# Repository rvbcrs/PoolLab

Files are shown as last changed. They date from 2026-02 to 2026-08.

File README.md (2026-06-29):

## Pura — ESP32‑S3 zwembadmonitor (pH, ORP, Temp · LVGL · MQTT · Zigbee)

### Wat het doet
- **pH en ORP meten** via analoge PH‑4502C/ORP‑4502C sensorbordjes (MCP6002 op 3.3 V) rechtstreeks op de ESP32 ADC.
- **Twee modi**: schakel tussen **Zigbee** en **WiFi/MQTT** via een UI‑toggle. De keuze wordt persistent opgeslagen (NVS) en bij boot toegepast.
- **MQTT integratie**: publiceert pH/ORP/temperatuur en biedt Home Assistant auto‑discovery + command topics om drempels te wijzigen.
- **Doseer‑pompen**: twee peristaltische pompen (pH/ORP) via TB6612FNG driver, met PWM‑snelheidsregeling vanuit de LVGL‑UI.
- **Safety**: limieten voor dagvolume, sessieduur en pH/ORP sanity; automatische noodstop + WhatsApp‑notificatie.
- **Zigbee commissioning**: lange druk op BOOT (>3 s) start commissioning; WiFi wordt tijdelijk uitgezet.

---

### Primaire hardware

| Onderdeel | Omschrijving |
|---|---|
| **MCU** | JC3248W535 — ESP32‑S3, 3.5" IPS 320×480 QSPI display, capacitief touch |
| **Sensoren** | 2× PH‑4502C bordje (één voor pH, één voor ORP), LM358 vervangen door **MCP6002** |
| **Motor driver** | SparkFun ROB‑14450 / TB6612FNG |
| **Pompen** | 2× peristaltische pomp (pH‑dosering en ORP/chloor‑dosering) |

---

### Sensor bekabeling (PH‑4502C met MCP6002 op 3.3 V)

> **Belangrijk:** Voed het bordje op **3.3 V**, niet 5 V.
> De MCP6002 is rail‑to‑rail (1.8–6 V). Bij 5 V kan de analoge output bij zuur water boven 3.3 V uitkomen en de ESP32 ADC beschadigen.

```
PH‑4502C (pH bordje)        JC3248W535 (ESP32‑S3)
  VCC  ──────────────────────  3.3 V
  GND  ──────────────────────  GND
  PO   ──────────────────────  GPIO6   (ADC1_CH5)
  DO   niet aansluiten
  TO   niet aansluiten
  BNC  ←── pH‑electrode

PH‑4502C (ORP bordje)       JC3248W535 (ESP32‑S3)
  VCC  ──────────────────────  3.3 V
  GND  ──────────────────────  GND
  PO   ──────────────────────  GPIO7   (ADC1_CH6)
  DO   niet aansluiten
  TO   niet aansluiten
  BNC  ←── ORP‑electrode
```

GPIO6 en GPIO7 zijn vrije ADC1‑pinnen (geen WiFi‑conflict). De overige ADC1‑pinnen zijn in gebruik door QSPI‑display (21/39/40/45/47/48), touch I2C (4/8), motoren (9/14–18) en I2S‑speaker (2/41/42).

**Testen zonder probe:**
Verbind de BNC center pin met de BNC outer ring via een 10 kΩ weerstand → simuleert 0 mV (pH 7 / 0 mV ORP) → de display toont ~pH 7.0 en ~0 mV.

**Platformio.ini flags (al ingesteld voor `esp32‑s3‑35`):**
```ini
-D USE_ANALOG_SENSORS=1
-D PH_ADC_PIN=6
-D ORP_ADC_PIN=7
```

**Kalibratie defaults (MCP6002 op 3.3 V, gain ≈ 5.2×):**
| Punt | Spanning |
|---|---|
| pH 4 | ≈ 2.58 V |
| pH 7 | ≈ 1.65 V (mid‑supply) |
| pH 10 | ≈ 0.72 V |
| ORP 0 mV | ≈ 1.65 V |

Kalibreer altijd met pH 4 en pH 7 buffervloeistof voor nauwkeurige metingen. Waarden worden opgeslagen in NVS via WebUI → Settings → Calibration.

---

### Wiring diagrams

**ESP32‑S3 — Analoge sensoren (PH‑4502C met MCP6002)**

```mermaid
flowchart LR
  PH_PROBE["pH‑electrode\n(BNC)"] --> PH_BOARD["PH‑4502C\n(MCP6002 op 3.3 V)"]
  ORP_PROBE["ORP‑electrode\n(BNC)"] --> ORP_BOARD["PH‑4502C ORP\n(MCP6002 op 3.3 V)"]
  PH_BOARD  --"PO → GPIO6"--> MCU["JC3248W535\nESP32‑S3"]
  ORP_BOARD --"PO → GPIO7"--> MCU
  V33["3.3 V"] --> PH_BOARD
  V33         --> ORP_BOARD
  GND["GND"]  --> PH_BOARD
  GND         --> ORP_BOARD
  GND         --> MCU
```

**ESP32‑C6 — ADS1115 via I2C**

```mermaid
flowchart LR
  PH_PROBE["pH‑electrode\n(BNC)"] --> PH_BOARD["PH‑4502C"]
  ORP_PROBE["ORP‑electrode\n(BNC)"] --> ORP_BOARD["PH‑4502C ORP"]
  PH_BOARD  --"AO → A0"--> ADS["ADS1115\n(0x48)"]
  ORP_BOARD --"AO → A1"--> ADS
  ADS --"SDA → GPIO18"--> MCU["ESP32‑C6"]
  ADS --"SCL → GPIO19"--> MCU
  V33["3.3 V"] --> ADS
  GND["GND"]   --> ADS
  GND          --> MCU
```

**ESP32‑S3 — Motor driver (TB6612FNG)**

```mermaid
flowchart LR
  MCU["JC3248W535\nESP32‑S3"] --"GPIO15 IN1\nGPIO16 IN2\nGPIO17 PWM"--> M1["TB6612\nMotor A"]
  MCU --"GPIO18 IN1\nGPIO14 IN2\nGPIO9 PWM"--> M2["TB6612\nMotor B"]
  MCU --"GPIO46 STBY"--> M1
  MCU --"GPIO46 STBY"--> M2
  M1 --"A01/A02"--> PUMP1["pH‑pomp"]
  M2 --"B01/B02"--> PUMP2["ORP‑pomp"]
  VM["6–12 V"] --> M1
  VM           --> M2
```

---

### ADS1115 (ESP32‑C6 build)

De C6‑build (`esp32‑c6‑147`) leest pH en ORP via een ADS1115 16‑bit ADC op I2C:

```
ADS1115          ESP32‑C6
  VDD ────────── 3.3 V
  GND ────────── GND
  SDA ────────── GPIO18
  SCL ────────── GPIO19
  A0  ────────── pH AO
  A1  ────────── ORP AO
```

Flags (al ingesteld):
```ini
-D USE_ADS1115=1
-D ADS_ADDR=0x48
-D ADS_SDA=18
-D ADS_SCL=19
-D ADS_CH_PH=0
-D ADS_CH_ORP=1
```

---

### Motor driver bekabeling (TB6612FNG — ESP32‑S3)

```
TB6612FNG        JC3248W535 (ESP32‑S3)
  VCC  ────────── 3.3 V  (logica)
  GND  ────────── GND
  VM   ────────── motorspanning (6–12 V)
  STBY ────────── GPIO46

  AIN1 ────────── GPIO15  (M1 IN1 / pH pomp)
  AIN2 ────────── GPIO16  (M1 IN2)
  PWMA ────────── GPIO17  (M1 PWM — LEDC CH5 / Timer 3)

  BIN1 ────────── GPIO18  (M2 IN1 / ORP pomp)
  BIN2 ────────── GPIO14  (M2 IN2)
  PWMB ────────── GPIO9   (M2 PWM — LEDC CH4 / Timer 2)

  A01/A02 ─────── Motor 1 (pH‑pomp)
  B01/B02 ─────── Motor 2 (ORP‑pomp)
```

- GPIO46 is een strapping pin; zorg dat STBY niet omlaag trekt tijdens boot.
- PWM: 10 kHz, 8‑bit. Snelheden instelbaar in LVGL‑UI en opgeslagen in NVS.

---

### Pump Flow Tracking & Kalibratie

**Wat wordt bijgehouden:**
- Real‑time flow rate (ml/min) tijdens pompen
- Session volume (ml) — reset bij stop
- Daily volume — reset automatisch om 00:00
- Total volume — handmatig reset via WebUI

**Flow kalibreren:**
1. WebUI → Settings → "Pump Flow Rate (ml/min @ 100%)"
2. Laat pomp 60 s @ 100% draaien, meet volume in maatbeker
3. Flow rate = gemeten volume / 1 minuut
4. Systeem schaalt automatisch voor lagere snelheden (bijv. 60% = 0.6 × gekalibreerde waarde)

---

### Safety Features & Emergency Stop

**Limieten (instelbaar in `src/main.cpp`):**
```cpp
MAX_DAILY_VOLUME     = 500.0f;  // ml/dag per pomp
MAX_SESSION_VOLUME   = 200.0f;  // ml per aanslag
MAX_SESSION_DURATION = 120;     // seconden per aanslag
PH_SANITY_MIN        = 4.0f;
PH_SANITY_MAX        = 10.0f;
ORP_SANITY_MIN       = -500.0f;
ORP_SANITY_MAX       = 1500.0f;
SENSOR_TIMEOUT       = 300;     // seconden zonder data → alarm
```

**Gedrag bij trigger:**
- Alle pompen direct gestopt
- Rode banner op LVGL UI: `⚠️ EMERGENCY STOP - <reden>`
- MQTT alert op `pool/alert/<type>`
- WhatsApp‑bericht via CallMeBot

**WhatsApp Setup (CallMeBot):**
1. Verkrijg API key via https://www.callmebot.com/blog/free-api-whatsapp-messages/
2. WebUI → Safety → telefoonnummer (bijv. `31612345678`) + API key invullen
3. Test via "Send Test Alert" button

**MQTT Alert Topics:**
```
pool/alert/daily_limit_m1      pool/alert/daily_limit_m2
pool/alert/session_volume_m1   pool/alert/session_volume_m2
pool/alert/session_duration_m1 pool/alert/session_duration_m2
pool/alert/ph_sanity_low       pool/alert/ph_sanity_high
pool/alert/orp_sanity_low      pool/alert/orp_sanity_high
pool/alert/ph_sensor_timeout   pool/alert/orp_sensor_timeout
```

---

### Bouwen en flashen

Primaire build (ESP32‑S3 35"):
```bash
pio run -e esp32-s3-35 -t upload --upload-port <ip>   # OTA
pio run -e esp32-s3-35 -t upload                       # USB
```

C6 build:
```bash
pio run -e esp32-c6-147 -t upload
```

Seriële monitor: 115200 baud.

---

### Configuratie

**WiFi** via captive portal:
- Bij lege WiFi‑gegevens start automatisch AP `Pura‑Setup`.
- Verbind → open willekeurige URL → vul SSID/wachtwoord in → Save & Reboot.
- Of via Settings → Network → Configure WiFi.

**MQTT** instelbaar via WebUI → Settings (host/port/user/pass) of in `src/main.cpp`:
```cpp
MQTT_HOST, MQTT_PORT, MQTT_USER, MQTT_PASS, MQTT_CLIENTID
```

**OTA:** hostnaam `pura-XXXXXX` (chip‑ID). Upload via PlatformIO "Upload using network" of ArduinoOTA.

---

### MQTT Topics

State:
```
pool/sensor/ph
pool/sensor/orp
pool/sensor/temp
```

Home Assistant discovery:
```
homeassistant/sensor/pool_ph/config
homeassistant/sensor/pool_orp/config
homeassistant/sensor/pool_temp/config
```

Drempels (write/echo):
```
pool/cmd/ph_min  ↔  pool/cfg/ph_min
pool/cmd/ph_max  ↔  pool/cfg/ph_max
pool/cmd/orp_min ↔  pool/cfg/orp_min
pool/cmd/orp_max ↔  pool/cfg/orp_max
```

---

### WebUI

| URL | Pagina |
|-----|---|
| `http://<ip>/` | Live sensor tiles + pump stats (WebSocket) |
| `http://<ip>/settings` | pH/ORP drempels, pompsnelheden, flow kalibratie, MQTT |
| `http://<ip>/safety` | Emergency status, WhatsApp config, volume resets, test alerts |

WebSocket op poort 81.

---

### LVGL UI

- **ESP32‑S3 (3.5"):** 3‑card UI (pH / ORP / Temp), moderne donkere tegels, pump stats boven motoricoon, emergency banner.
- **ESP32‑C6 (1.47"):** Compacte tileview (pH/ORP).
- Watchdog S3: heartbeat uit BSP‑task; herbouwt UI als >8 s stil → `S3 LVGL watchdog: rebuild complete`.
- Touch: debouncing ingebouwd, geen key‑repeat.

---

### Projectstructuur

| Bestand | Rol |
|---|-----|
| `src/main.cpp` | Bootvolgorde, WiFi/MQTT, Zigbee, periodic publish, safety |
| `src/core/Storage.{h,cpp}` | NVS wrapper (drempels, snelheden, modus, volumes, config) |
| `src/core/boards/Esp32S3Board.{h,cpp}` | S3 board: display, touch, pins, LVGL lock |
| `src/core/boards/Esp32C6Board.{h,cpp}` | C6 board |
| `src/boards/BoardSelect.{h,cpp}` | Board‑selectie op basis van build flag |
| `src/domain/Metrics.{h,cpp}` | Laatste pH/ORP/temp; bron voor UI en MQTT |
| `src/domain/ControlPolicy.{h,cpp}` | Safety logic, sanity checks, emergency stop |
| `src/io/AnalogPhOrpSensor.h` | ADC‑lezer voor PH‑4502C via ESP32 ADC (S3) |
| `src/io/AdsPhOrpSensor.{h,cpp}` | ADS1115 I2C lezer voor pH/ORP (C6) |
| `src/io/MotorController.h` | Motor state machine, LEDC PWM, flow tracking |
| `src/io/MqttClient.{h,cpp}` | PubSubClient: discovery, publish, command topics, alerts |
| `src/io/WebUI.{h,cpp}` | Async web server: homepage, settings, safety, WebSocket, API |
| `src/io/ZigbeeClient.{h,cpp}` | Zigbee abstractie (C6; no‑op op S3) |
| `src/ui/UI.{h,cpp}` | LVGL UI builder (3‑card S3 / tileview C6), emergency banner |
| `src/domain/DummySensor.h` | Gesimuleerde sensordata voor testen |
| `src/fonts`, `src/images` | LVGL assets (fonts, iconen) |

---

### Troubleshooting

**pH/ORP waarden kloppen niet:**
- Kalibreer met pH 4 en pH 7 buffervloeistof via WebUI → Settings → Calibration.
- Check de spanning op PO met een multimeter: bij VCC=3.3 V moet pH 7 ≈ 1.65 V geven.
- Zorg dat VCC van het sensorbordje echt 3.3 V is (niet 5 V).

**WiFi "NO_AP_FOUND":** controleer SSID/ontvangst; auto‑reconnect + periodieke hard restart.

**MQTT extern werkt niet, lokaal wel:**
- Cloudflare DNS: zet op "DNS only" (grijze wolk) voor raw TCP.
- NPM: gebruik Streams (TCP), geen Proxy Host.
- Test met `mosquitto_sub/pub` voordat je het device test.

**Pompen werken niet:**
- Console: `[MOTOR] Check: MOTOR_ENABLE=1 motorsEnabled=?` — beide moeten 1 zijn.
- WebUI → Settings → vink "Enable pH/ORP dosing pumps" aan → Save.

**Emergency stop reset niet automatisch:**
- Sanity alerts: wacht tot sensorwaarden terug binnen limieten zijn.
- Volume/duration limits: reset device of wacht tot 00:00 (daily reset).

**WhatsApp notificaties werken niet:**
- Telefoonnummer met landcode (bijv. `31612345678`).
- Test via CallMeBot website om te bevestigen dat account actief is.
- Console: zoek naar `[SAFETY] WhatsApp API response: 200`.

---

### Changelog

**Huidig:**
- ✅ Tuya UART sniffer verwijderd — alle sensordata nu via directe hardware (ADC / ADS1115).
- ✅ PH‑4502C analoge sensoren op GPIO6 (pH) en GPIO7 (ORP) — MCP6002 op 3.3 V.
- ✅ Kalibratie defaults aangepast voor MCP6002 op 3.3 V (mid‑supply = 1.65 V).
- ✅ Zigbee `onPh/OrpMinMaxWrite` stubs voor non‑Zigbee builds (fix compile‑fout S3).
- ✅ `core::Board.h` include toegevoegd aan `UI.cpp` (fix `UiConfig` compile‑fout).
- ✅ Backup‑bestanden opgeruimd (`AnalogPhOrpSensor 2.h`, `AdsPhOrpSensor 2.*`).

**Eerder:**
- ✅ Pump flow tracking: ml/min, session, daily (auto‑reset 00:00), total.
- ✅ Safety limits: daily/session volume, session duration, pH/ORP sanity, sensor timeout.
- ✅ Emergency stop: noodstop + rode LVGL banner.
- ✅ WhatsApp notificaties via CallMeBot (async task).
- ✅ MQTT alert topics `pool/alert/<type>`.
- ✅ WebUI Safety page, Settings gereorganiseerd met emoji‑headers.
- ✅ Unieke MQTT clientId per device (chip‑ID).
- ✅ Exponential backoff bij MQTT reconnect.
- ✅ LVGL watchdog voor C6 en S3.
- ✅ Touch debouncing (geen key‑repeat).
- ✅ Reset WiFi knop via captive portal.

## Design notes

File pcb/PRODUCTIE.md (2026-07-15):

# Pura mainboard — van bron naar productie-PCB (rev 0.3, 0805)

Flow: **`python3 build_flow.py`** — tscircuit (bron) → KiCad → freerouting (headless) → DRC-schoon board, volautomatisch. Daarna alleen nog silk/gerbers/bestellen.
Klaarstaand voor deze revisie: map **`pura-mainboard-0805-0.3.kicad/`** (met GND-zones + het **nieuwe rev 0.3 AGND-eiland** uit `port_zones.py`, al gevuld en DRC-gecheckt)
**Verificatiestatus: zie `VERIFICATIE-0.3.md`** — alle import-pinmappings, pin-coverage en custom lands zijn datasheet-geverifieerd.

## 0. Openstaande beslissingen (vóór je begint)

- [x] **C_OUT**: besloten — **220µF/16V SMD-elco (Ø6.3 V-chip)**, zit in de 0.3-bron. Polariteit: **pin 1 = +** naar de 5V-rail; de zwarte minstreep van de cup hoort aan de GND-kant.
- [ ] **Elco-maat meten**: TME-nummers zijn **EEE-1EA101XP / EEE-1CA221XP** (X = Ø6.3 case D8). De varianten *zonder* X zijn Ø8 en passen NIET op de lands. Meet ook de al via Ali bestelde 100 µF (moet Ø6.3 zijn).
- [ ] **LCSC-nummers invullen** in `pura-bom.csv` voor alle `TBD`-regels (0805-weerstanden/condensatoren/LEDs, 100µF 25V, 24k). Alleen nodig bij JLC-assembly; bij handmontage met AliExpress-onderdelen (Component Bench) niet.
- [x] Klopt de **24k op CFG1** met de CH224K-datasheet-tabel (6.8k=9V, **24k=12V**, 56k=15V)? ✔ Nagelezen én pin 9=CFG1 in de footprint geverifieerd tegen de pinout-figuur (§4.1) — zie `VERIFICATIE-0.3.md`.

## 1–4. Volautomatische flow: `build_flow.py`

Alles van tsx-bron tot geroute, DRC-schoon board is één commando:

```bash
cd pcb
python3 build_flow.py              # hele flow (incl. tsci-export)
python3 build_flow.py --no-export  # tsx ongewijzigd: sla de export over
```

De flow doet achtereenvolgens:

1. **tsci-export** (kicad_zip) + hernoemen naar de 0.3-bestandsnamen
2. **netklassen + rules** in de `.kicad_pro`: Default 0.2 mm (via 0.6/0.3), **POWER 0.6 mm** (via 0.8/0.4) voor 12V-VBUS, buck-switchnode, 5V-rail en de 4 motoruitgangen; min. track/clearance 0.15, edge 0.4, thermal spokes 1. (tsci schrijft schema-v1; de flow normaliseert naar v5, anders dropt KiCad de klasse-toewijzingen!)
3. **zones porten** (`port_zones.py`): GND prio 1/2 + AGND-eiland v2, tsci's auto-zones eruit
4. **gelockte pre-routes** (`preroute_iso.py`, met eigen clearance-validator): iso-netten binnen het eiland, AIN0/AIN1 (pH/ORP) door de gang onderlangs, en het complete AGND-stitching-raamwerk (pad-verankerd)
5. **3D-modellen** injecteren voor de custom footprints (L1 → `L_APV_ANR6045`, C_IN/C_OUT → `CP_Elec_6.3x7.7`)
6. **DSN bouwen** (tijdelijke kopie zonder zones, clearance 0.17 als afrondmarge)
7. **freerouting headless** (`~/Downloads/freerouting-1.7.0.jar`, `-mp 200`) — de gelockte sporen gaan als `type fix` mee en blijven staan
8. **ses importeren** + opschonen (AGND-sporen buiten het eiland weg, dubbelen weg) + zone-fill + **adaptieve AGND-stitching** (raster-vias, alleen waar beide lagen fill hebben)
9. **DRC-gate**: faalt hard op unconnected/clearance/shorts/edge; silk/tekst-cosmetica mag

> ⚠️ De freerouting-**GUI** (v2.2.4) crasht met `StackOverflowError` op deze DSN — daarom headless met de 1.7.0-jar. Niet meer handmatig DSN'en/importeren.
> ⚠️ Handmatige board-edits (silk, verplaatsingen) overleven een flow-run **niet** — de bron is de tsx. Backups: `*.goodhand.bak` e.d. in de kicad-map.
> Los valideren van de bron kan nog steeds: `npx tsci export pura-mainboard-noroute.tsx -f circuit-json -o circuit.json` (0 errors verwacht).

Na de flow: board openen in KiCad voor de visuele check + silkscreen/logo/versienummer **v0.3**, daarna stap 5.

## 5. Productiebestanden exporteren (KiCad)

**Gerbers** — `File > Fabrication Outputs > Gerbers`:
- Lagen: F.Cu, B.Cu, F.Mask, B.Mask, F.Silkscreen, B.Silkscreen, Edge.Cuts
- Opties: Protel-extensies **uit**, "subtract soldermask from silk" **aan**
- `Generate Drill Files`: Excellon, PTH+NPTH samengevoegd mag
- Alles in één map → zip: `pura-mainboard-0805-0.3-gerbers.zip`

**Assembly (alleen bij JLC-SMT):**
- BOM: `pura-bom.csv` (eerst TBD's → echte LCSC-nummers; kolommen Designator/Comment/Footprint/LCSC)
- CPL: `File > Fabrication Outputs > Component Placement (.pos)` → CSV met kolommen `Designator, Mid X, Mid Y, Layer, Rotation` (JLC-format, zie `pura-cpl-jlcpcb.csv` van rev 0.2 als voorbeeld)

> ⚠️ `make_bom.py` **overschrijft** de handmatig verrijkte `pura-bom.csv` — niet draaien tenzij je de LCSC-kolom opnieuw wilt invullen.

## 6. Bestellen bij JLCPCB

1. Gerber-zip uploaden → controleer de render (outline 50×50 mm, 2 lagen)
2. PCB-opties: 1.6 mm FR-4, 2 laags, HASL of ENIG, kleur naar smaak — verder defaults
3. **Met assembly**: SMT Assembly aanvinken (top side) → BOM + CPL uploaden → parts matchen (streef naar basic parts voor de passives; extended = ~$3 setup per uniek onderdeel) → **placement-preview**: rotaties van U1–U6, D1, LEDs en J1 visueel controleren en zo nodig draaien (tab-fouten hier = dode boards)
4. **Zonder assembly** (handmontage): alleen de gerber-zip; onderdelen bestel je via de Component Bench (`python3 ali_server.py`) — zie `pura-self-source.csv`
5. DFM-opmerkingen van JLC afwachten → bevestigen

## 7. Bring-up checklist (als de boards binnen zijn)

1. Visuele inspectie: bruggen bij U3 (VSSOP-10, 0.5 mm pitch) en U4 (SSOP-24)
2. Multimeter, **vóór** aansluiten: geen kortsluiting VBUS↔GND, 5V↔GND, AGND↔GND (moet ~∞, AGND↔GND alleen via de isolatie gescheiden)
3. USB-C PD-lader aansluiten → **VBUS = 12 V** meten (dit valideert de CFG1/24k-fix; 5 V = config fout)
4. 5V-rail meten na de LM2596 (4.9–5.1 V), rimpel checken als je een scoop hebt
5. ESP + firmware: I²C-scan moet de ADS1115 op **0x48** zien (valideert R_ADDR/soldeerbrug)
6. Pompen los testen op de TB6612-uitgangen (12 V blokgolf bij PWM)
7. pH/ORP-proefmeting via de geïsoleerde ingang; waardes vergelijken met buffer

## Bekende afwijkingen t.o.v. rev 0.2 (de geproduceerde boards)

| Wat | rev 0.2 (besteld) | rev 0.3 (deze flow) |
|---|---|---|
| Passives | 0402/0603 | **0805** |
| CH224K config | 0R op CFG2 → vraagt 5 V (bug!) | **24k op CFG1 → 12 V** |
| C_IN | C15008 = 6.3 V (te laag op 12 V-rail) | **100µF 25 V** |
| C_OUT | C15008 (MLCC) | **220µF 16 V SMD-elco** (Ø6.3) |
| L1 | 33µH **1210, 70mA** (RF-choke!) | **33µH CD54 power-inductor ~0.7A** (5.8×5.2mm) |
| CH224K-voeding | VDD **direct aan 12 V** (abs max 3,6 V — chip sterft!) | **1 kΩ serie + 1 µF** (R_VDD/C_VDD), VBUS-sense via **10 kΩ** (R_VSNS) |
| CC-pulldowns | externe 5,1 kΩ (fout: Rd zit intern) | **vervallen** — CC1/CC2 direct |
| DP/DM | zwevend | **kortgesloten** (PD-only, datasheet §5.5) |
| TB6612 VCC | 5 V (VIH=3,5 V > 3,3 V ESP: buiten spec) | **3,3 V via nieuwe V33-pin** op J_ESP (11-pins!) |
| ADuM1250 | ESP aan side 1 (VOL 0,9 V > ESP-drempel) | **omgedraaid**: ESP aan side 2 @3,3 V + pull-ups R_SDA2/R_SCL2 |
| B0505S | geen minimumbelasting (Vout kan ~6 V worden) | **R_BLD 330 Ω** op V5_ISO |

> ⚠️ **Rev 0.2-boards: de PD-sectie is NIET veilig te bodgen.** Naast de CFG-fout ligt daar CH224K-VDD **rechtstreeks aan 12 V** (abs max 3,6 V) — de chip gaat direct stuk zodra een PD-lader 12 V levert. Repareren vergt trace-snijden + 2 weerstanden + zijden-swap van de ADuM: niet realistisch. Gebruik rev 0.2 hooguit als soldeeroefening; bouw op rev 0.3.

**Let op de ESP-kabel:** J_ESP is nu **11-pins** — er is een **V33-ader bij** (3,3 V vanuit de ESP-module) die TB6612 en de ADuM-ESP-kant voedt. Zonder die ader doen de pompen en de I²C het niet.

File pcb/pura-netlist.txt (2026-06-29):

COMPONENTS:
 - J1: TYPE_C_16PIN_2MD_073_
 - U1: CH224K
 - R_CC1: 5.1kΩ res0402 resistor
 - R_CC2: 5.1kΩ res0402 resistor
 - R_CFG2: 0Ω res0402 resistor
 - C_VDD: 100nF 0402 capacitor
 - C_IN: 220uF 1210 capacitor
 - U2: LM2596S_5_0_UMW_
 - C_OUT: 220uF 1210 capacitor
 - D1: D1, source_component
 - L1: L1, source_component
 - C_DC_IN: 10uF 0603 capacitor
 - U5: B0505S_1WR3
 - C_DC_OUT: 10uF 0603 capacitor
 - C_ISO1: 100nF 0402 capacitor
 - U6: ADUM1250ARZ_RL7
 - C_ISO2: 100nF 0402 capacitor
 - R_SDA: 4.7kΩ res0402 resistor
 - R_SCL: 4.7kΩ res0402 resistor
 - U3: ADS1115IDGST
 - C_ADS: 100nF 0402 capacitor
 - R_ADDR: 0Ω res0402 resistor
 - C_VM: 10uF 0603 capacitor
 - U4: TB6612FNG_C_8_EL
 - C_VCC: 100nF 0402 capacitor
 - R_LED: 2.2kΩ res0402 resistor
 - LED1: LED1, source_component
 - R_LED2: 2.2kΩ res0402 resistor
 - LED2: LED2, source_component
 - J_ESP: J_ESP, source_component
 - J_PROBE: J_PROBE, source_component
 - J_M1: J_M1, source_component
 - J_M2: J_M2, source_component
 - J_12V: J_12V, source_component

NET: R_CC1_pos
  - J1 B5
  - U1 CC1
  - R_CC1 pin1

NET: R_CC2_pos
  - J1 A5
  - U1 CC2
  - R_CC2 pin1

NET: R_CFG2_pos
  - U1 CFG2
  - R_CFG2 pin1

NET: U2_OUT
  - U2 OUT
  - L1 pin1 (+)
  - D1 pin2 (-)

NET: LED1_pos
  - R_LED pin2
  - LED1 pin1 (+)

NET: LED2_pos
  - R_LED2 pin2
  - LED2 pin1 (+)

NET: U3_VDD
  - C_ISO2 pin1 (+)
  - U5 pin4
  - U6 VDD2
  - U3 VDD
  - J_PROBE V5_ISO
  - R_LED2 pin1
  - C_DC_OUT pin1 (+)
  - R_SDA pin2
  - R_SCL pin2
  - C_ADS pin1 (+)

NET: U3_ADDR
  - U3 ADDR
  - R_ADDR pin1

NET: AGND
  - R_ADDR pin2
  - C_ADS pin2 (-)
  - C_ISO2 pin2 (-)
  - C_DC_OUT pin2 (-)
  - LED2 pin2 (-)
  - U5 pin3
  - U6 GND2
  - U3 GND
  - J_PROBE AGND

NET: U3_SDA
  - U3 SDA
  - R_SDA pin1
  - U6 SDA2

NET: U3_SCL
  - U3 SCL
  - R_SCL pin1
  - U6 SCL2

NET: J_PROBE_PH_PO
  - U3 AIN0
  - J_PROBE PH_PO

NET: J_PROBE_ORP_PO
  - U3 AIN1
  - J_PROBE ORP_PO

NET: J_ESP_SDA
  - J_ESP SDA
  - U6 SDA1

NET: J_ESP_SCL
  - J_ESP SCL
  - U6 SCL1

NET: GND
  - C_VCC pin2 (-)
  - C_VM pin2 (-)
  - C_ISO1 pin2 (-)
  - C_DC_IN pin2 (-)
  - LED1 pin2 (-)
  - U2 EP
  - U2 pin5
  - C_OUT pin2 (-)
  - D1 pin1 (+)
  - C_IN pin2 (-)
  - U2 GND
  - C_VDD pin2 (-)
  - R_CFG2 pin2
  - R_CC2 pin2
  - R_CC1 pin2
  - U1 GND
  - J1 A1B12
  - J1 B1A12
  - J1 EH1
  - J1 EH2
  - U4 GND
  - U4 PGND11
  - U4 PGND21
  - J_ESP GND
  - J_12V GNDP
  - U6 GND1
  - U5 pin1

NET: U1_VDD
  - C_IN pin1 (+)
  - U1 VDD
  - U1 VBUS
  - C_VDD pin1 (+)
  - J1 A4B9
  - J1 B4A9
  - U2 VIN
  - U4 VM1
  - J_12V VIN12
  - C_VM pin1 (+)
  - U4 VM2
  - U4 VM3

NET: U4_PWMA
  - U4 PWMA
  - J_ESP PWMA

NET: U4_PWMB
  - U4 PWMB
  - J_ESP PWMB

NET: U4_AIN1
  - U4 AIN1
  - J_ESP AIN1

NET: U4_AIN2
  - U4 AIN2
  - J_ESP AIN2

NET: U4_BIN1
  - U4 BIN1
  - J_ESP BIN1

NET: U4_BIN2
  - U4 BIN2
  - J_ESP BIN2

NET: U2_FB
  - U4 STBY
  - C_ISO1 pin1 (+)
  - L1 pin2 (-)
  - U2 FB
  - C_OUT pin1 (+)
  - U4 VCC
  - J_ESP V5
  - U6 VDD1
  - U5 pin2
  - R_LED pin1
  - C_DC_IN pin1 (+)
  - C_VCC pin1 (+)

NET: U4_AO11
  - U4 AO11
  - J_M1 MA1

NET: U4_AO21
  - U4 AO21
  - J_M1 MA2

NET: U4_BO11
  - U4 BO11
  - J_M2 MB1

NET: U4_BO21
  - U4 BO21
  - J_M2 MB2

COMPONENT_PINS:
J1 (TYPE_C_16PIN_2MD_073_)
- pin1: NOT_CONNECTED
- pin2: NOT_CONNECTED
- pin3: NOT_CONNECTED
- pin4: NOT_CONNECTED
- pin5: NOT_CONNECTED
- pin6: NOT_CONNECTED
- pin7: NOT_CONNECTED
- pin8: NOT_CONNECTED
- pin9: NOT_CONNECTED
- pin10: NOT_CONNECTED
- pin11: NOT_CONNECTED
- pin12: NOT_CONNECTED
- pin13(EH1): NETS(GND)
- pin14(EH2): NETS(GND)
- pin15(pin13_alt1): NOT_CONNECTED
- pin16(pin14_alt1): NOT_CONNECTED
- pin17(A1B12): NETS(GND)
- pin18(A4B9): NETS(U1_VDD)
- pin19(B8): NOT_CONNECTED
- pin20(A5): NETS(R_CC2_pos)
- pin21(B7): NOT_CONNECTED
- pin22(A6): NOT_CONNECTED
- pin23(A7): NOT_CONNECTED
- pin24(B6): NOT_CONNECTED
- pin25(A8): NOT_CONNECTED
- pin26(B5): NETS(R_CC1_pos)
- pin27(B4A9): NETS(U1_VDD)
- pin28(B1A12): NETS(GND)

U1 (CH224K)
- pin1(VDD): NETS(U1_VDD)
- pin2(CFG2): NETS(R_CFG2_pos)
- pin3(CFG3): NOT_CONNECTED
- pin4(DP): NOT_CONNECTED
- pin5(DM): NOT_CONNECTED
- pin6(CC2): NETS(R_CC2_pos)
- pin7(CC1): NETS(R_CC1_pos)
- pin8(VBUS): NETS(U1_VDD)
- pin9(CFG1): NOT_CONNECTED
- pin10(PG): NOT_CONNECTED
- pin11(GND): NETS(GND)

R_CC1 (5.1kΩ res0402)
- pin1(anode, pos, left): NETS(R_CC1_pos)
- pin2(cathode, neg, right): NETS(GND)

R_CC2 (5.1kΩ res0402)
- pin1(anode, pos, left): NETS(R_CC2_pos)
- pin2(cathode, neg, right): NETS(GND)

R_CFG2 (0Ω res0402)
- pin1(anode, pos, left): NETS(R_CFG2_pos)
- pin2(cathode, neg, right): NETS(GND)

C_VDD (100nF 0402)
- pin1(pos, anode, left): NETS(U1_VDD)
- pin2(neg, cathode, right): NETS(GND)

C_IN (220uF 1210)
- pin1(pos, anode, left): NETS(U1_VDD)
- pin2(neg, cathode, right): NETS(GND)

U2 (LM2596S_5_0_UMW_)
- pin1(VIN): NETS(U1_VDD)
- pin2(OUT): NETS(U2_OUT)
- pin3(GND): NETS(GND)
- pin4(FB): NETS(U2_FB)
- pin5: NETS(GND)
- pin6(EP): NETS(GND)

C_OUT (220uF 1210)
- pin1(pos, anode, left): NETS(U2_FB)
- pin2(neg, cathode, right): NETS(GND)

D1 (SS34)
- pin1(pos, anode, left): NETS(GND)
- pin2(neg, cathode, right): NETS(U2_OUT)

L1
- pin1(anode, pos, left): NETS(U2_OUT)
- pin2(cathode, neg, right): NETS(U2_FB)

C_DC_IN (10uF 0603)
- pin1(pos, anode, left): NETS(U2_FB)
- pin2(neg, cathode, right): NETS(GND)

U5 (B0505S_1WR3)
- pin1: NETS(GND)
- pin2: NETS(U2_FB)
- pin3: NETS(AGND)
- pin4: NETS(U3_VDD)

C_DC_OUT (10uF 0603)
- pin1(pos, anode, left): NETS(U3_VDD)
- pin2(neg, cathode, right): NETS(AGND)

C_ISO1 (100nF 0402)
- pin1(pos, anode, left): NETS(U2_FB)
- pin2(neg, cathode, right): NETS(GND)

U6 (ADUM1250ARZ_RL7)
- pin1(VDD1): NETS(U2_FB)
- pin2(SDA1): NETS(J_ESP_SDA)
- pin3(SCL1): NETS(J_ESP_SCL)
- pin4(GND1): NETS(GND)
- pin5(GND2): NETS(AGND)
- pin6(SCL2): NETS(U3_SCL)
- pin7(SDA2): NETS(U3_SDA)
- pin8(VDD2): NETS(U3_VDD)

C_ISO2 (100nF 0402)
- pin1(pos, anode, left): NETS(U3_VDD)
- pin2(neg, cathode, right): NETS(AGND)

R_SDA (4.7kΩ res0402)
- pin1(anode, pos, left): NETS(U3_SDA)
- pin2(cathode, neg, right): NETS(U3_VDD)

R_SCL (4.7kΩ res0402)
- pin1(anode, pos, left): NETS(U3_SCL)
- pin2(cathode, neg, right): NETS(U3_VDD)

U3 (ADS1115IDGST)
- pin1(ADDR): NETS(U3_ADDR)
- pin2: NOT_CONNECTED
- pin3(GND): NETS(AGND)
- pin4(AIN0): NETS(J_PROBE_PH_PO)
- pin5(AIN1): NETS(J_PROBE_ORP_PO)
- pin6(AIN2): NOT_CONNECTED
- pin7(AIN3): NOT_CONNECTED
- pin8(VDD): NETS(U3_VDD)
- pin9(SDA): NETS(U3_SDA)
- pin10(SCL): NETS(U3_SCL)

C_ADS (100nF 0402)
- pin1(pos, anode, left): NETS(U3_VDD)
- pin2(neg, cathode, right): NETS(AGND)

R_ADDR (0Ω res0402)
- pin1(anode, pos, left): NETS(U3_ADDR)
- pin2(cathode, neg, right): NETS(AGND)

C_VM (10uF 0603)
- pin1(pos, anode, left): NETS(U1_VDD)
- pin2(neg, cathode, right): NETS(GND)

U4 (TB6612FNG_C_8_EL)
- pin1(AO11): NETS(U4_AO11)
- pin2(AO12): NOT_CONNECTED
- pin3(PGND11): NETS(GND)
- pin4(PGND12): NOT_CONNECTED
- pin5(AO21): NETS(U4_AO21)
- pin6(AO22): NOT_CONNECTED
- pin7(BO21): NETS(U4_BO21)
- pin8(BO22): NOT_CONNECTED
- pin9(PGND21): NETS(GND)
- pin10(PGND22): NOT_CONNECTED
- pin11(BO11): NETS(U4_BO11)
- pin12(BO12): NOT_CONNECTED
- pin13(VM2): NETS(U1_VDD)
- pin14(VM3): NETS(U1_VDD)
- pin15(PWMB): NETS(U4_PWMB)
- pin16(BIN2): NETS(U4_BIN2)
- pin17(BIN1): NETS(U4_BIN1)
- pin18(GND): NETS(GND)
- pin19(STBY): NETS(U2_FB)
- pin20(VCC): NETS(U2_FB)
- pin21(AIN1): NETS(U4_AIN1)
- pin22(AIN2): NETS(U4_AIN2)
- pin23(PWMA): NETS(U4_PWMA)
- pin24(VM1): NETS(U1_VDD)

C_VCC (100nF 0402)
- pin1(pos, anode, left): NETS(U2_FB)
- pin2(neg, cathode, right): NETS(GND)

R_LED (2.2kΩ res0402)
- pin1(anode, pos, left): NETS(U2_FB)
- pin2(cathode, neg, right): NETS(LED1_pos)

LED1
- pin1(anode, pos, left): NETS(LED1_pos)
- pin2(cathode, neg, right): NETS(GND)

R_LED2 (2.2kΩ res0402)
- pin1(anode, pos, left): NETS(U3_VDD)
- pin2(cathode, neg, right): NETS(LED2_pos)

LED2
- pin1(anode, pos, left): NETS(LED2_pos)
- pin2(cathode, neg, right): NETS(AGND)

J_ESP
- pin1(V5): NETS(U2_FB)
- pin2(GND): NETS(GND)
- pin3(SDA): NETS(J_ESP_SDA)
- pin4(SCL): NETS(J_ESP_SCL)
- pin5(PWMA): NETS(U4_PWMA)
- pin6(PWMB): NETS(U4_PWMB)
- pin7(AIN1): NETS(U4_AIN1)
- pin8(AIN2): NETS(U4_AIN2)
- pin9(BIN1): NETS(U4_BIN1)
- pin10(BIN2): NETS(U4_BIN2)

J_PROBE
- pin1(V5_ISO): NETS(U3_VDD)
- pin2(AGND): NETS(AGND)
- pin3(PH_PO): NETS(J_PROBE_PH_PO)
- pin4(ORP_PO): NETS(J_PROBE_ORP_PO)

J_M1
- pin1(MA1): NETS(U4_AO11)
- pin2(MA2): NETS(U4_AO21)

J_M2
- pin1(MB1): NETS(U4_BO11)
- pin2(MB2): NETS(U4_BO21)

J_12V
- pin1(VIN12): NETS(U1_VDD)
- pin2(GNDP): NETS(GND)

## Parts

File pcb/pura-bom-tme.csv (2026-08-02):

Designator | Qty | Value | Footprint | Manufacturer | MPN | Bron | Note
R_CFG1 | 1 | 24k 1% | 0805 | Yageo | RC0805FR-0724KL | Ali (0603-set) | CH224K -> 12V request; 0603 uit assortiment op 0805-land
R_VDD | 1 | 1k 1% | 0805 | Yageo | RC0805FR-071KL | Ali (0603-set) | CH224K VDD-serieweerstand (shunt-reg, VERPLICHT per datasheet)
R_VSNS | 1 | 10k 1% | 0805 | Yageo | RC0805FR-0710KL | Ali (0603-set) | CH224K VBUS-sense serieweerstand (datasheet-eis)
R_BLD | 1 | 330 1% | 0805 | Yageo | RC0805FR-07330RL | Ali (0603-set) | B0505S minimum-belasting (ongeregelde uitgang)
R_SDA,R_SCL,R_SDA2,R_SCL2 | 4 | 4.7k 1% | 0805 | Yageo | RC0805FR-074K7L | Ali (0603-set) | I2C pull-ups (iso-kant naar 5V_iso; ESP-kant naar 3V3)
R_LED,R_LED2 | 2 | 2.2k 1% | 0805 | Yageo | RC0805FR-072K2L | Ali (0603-set) | LED-serieweerstand
R_ADDR | 1 | 0R | 0805 | Yageo | RC0805JR-070RL | Ali (0603-set) | ADS1115 adres 0x48 (of soldeerbrug)
C_ADS,C_ISO1,C_ISO2,C_VCC,C_VM2 | 5 | 100nF 50V X7R | 0805 | Yageo | CC0805KRX7R9BB104 | TME | ontkoppeling
C_VDD | 1 | 1uF 25V X7R | 0805 | Yageo | CC0805KKX7R8BB105 | TME | CH224K VDD-ontkoppeling (1uF per datasheet)
C_DC_IN,C_DC_OUT,C_VM | 3 | 10uF 25V X5R | 0805 | Murata | GRM21BR61E106KA73L | TME | ontkoppeling
C_IN | 1 | 100uF 25V alu-elco | SMD elco D8 (6.3x7.7) | Panasonic | EEE-1EA101XP | TME | buck-ingang (elektrolyt per LM2596-datasheet). 25V-keuze; de 16V EEEHC1C101XP is te krap op de 12V-rail. LET OP: variant *zonder* X is O8 en past NIET
C_OUT | 1 | 220uF 16V alu-elco | SMD elco D8 (6.3x7.7) | Samwha | SC1C227M6L07KVR | TME | LM2596-uitgang (ESR nodig!); O6.3x7.7 geverifieerd = D8-land. (Panasonic-alt: EEE-1CA221XP)
L1 | 1 | 33uH 1.5A | 6045 (6x6x4.5) | FerroCore | DJNR6045-330 | TME | buck-inductor; Ioper/Isat 1.5A, 188.5mOhm. 6x6-terminals vallen ~90% op het CD54-land (0.15mm overhang, prima handsoldeer). NIET de Ali 1210/70mA gebruiken - die verzadigt
LED1 | 1 | groen 0805 | 0805 | Wurth | 150080GS75000 | Ali (assort.) | power-LED; check 0805 groen in assortiment
LED2 | 1 | blauw 0805 | 0805 | Wurth | 150080BS75000 | Ali (assort.) | power-LED; check 0805 blauw in assortiment
D1 | 1 | SS34 | SMA / DO-214AC | Vishay | SS34-E3/57T | Ali | buck-freewheel schottky
U1 | 1 | CH224K | ESSOP-10 | WCH | CH224K | Ali | USB-PD sink; ESSOP-10 MET backplane (pad11=GND) - klopt. besteld
U2 | 1 | LM2596S-5.0 | TO-263-5 | Texas Instruments | LM2596SX-5.0/NOPB | Ali | 5V buck
U3 | 1 | ADS1115 | VSSOP-10 | Texas Instruments | ADS1115IDGSR | Ali | 16-bit ADC
U4 | 1 | TB6612FNG | SSOP-24 | Toshiba | TB6612FNG(O,C,8,EL) | Ali (module) | chip van de driver-module afsolderen. VERIFIEER: TB6612FNG (24-pins), NIET DRV8833 (16-pins)! TME-alt voor losse chip: TB6612FNG(O,C,8,EL)
U5 | 1 | B0505S-1WR3 | SIP | MORNSUN | B0505S-1WR3 | Ali | geisoleerde 5V/5V DC-DC 1W
U6 | 1 | ADUM1250ARZ | SOIC-8 | Analog Devices | ADUM1250ARZ | TME | geisoleerde I2C
J1 | 1 | USB-C 16P | TYPE-C-31-M-12 | HRO | TYPE-C-31-M-12 | Ali | USB-C 2.0 16-pins
J_ESP,J_PROBE,J_M1,J_M2,J_12V | 1 | pin header 1x40 2.54mm | THT 2.54mm | Wurth | 61304011121 | TME | knippen op 11/4/2/2/2 pins (J_ESP is 11-pins: V33 erbij!)

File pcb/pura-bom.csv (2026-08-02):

Designator | Comment | Footprint | LCSC Part #
J1 | USB-C 16P | TYPE-C-31-M-12 | C2765186
U1 | CH224K | ESSOP-10 | C970725
R_VDD | 1k (CH224K VDD-serie) | R0805
R_VSNS | 10k (VBUS-sense) | R0805
R_SDA2 | 4.7k (I2C ESP-kant) | R0805
R_SCL2 | 4.7k (I2C ESP-kant) | R0805
R_BLD | 330 (B0505S min-load) | R0805
C_VM2 | 100nF | C0805
U2 | LM2596S-5.0 | TO-263-5 | C347421
U3 | ADS1115 | VSSOP-10 | C468683
U4 | TB6612FNG | SSOP-24 | C141517
U6 | ADUM1250 | SOIC-8 | C13839
R_CFG1 | 24k (12V PD) | R0805 | TBD
R_SDA | 4.7k | R0805 | TBD
R_SCL | 4.7k | R0805 | TBD
R_ADDR | 0R | R0805 | TBD
R_LED | 2.2k | R0805 | TBD
R_LED2 | 2.2k | R0805 | TBD
C_VDD | 1uF | C0805 | TBD
C_ADS | 100nF | C0805 | TBD
C_ISO1 | 100nF | C0805 | TBD
C_ISO2 | 100nF | C0805 | TBD
C_VCC | 100nF | C0805 | TBD
C_IN | 100uF 25V elco SMD | SMD D8 6.3x7.7 (V-chip)
C_OUT | 220uF 16V elco SMD | SMD D8 6.3x7.7 (V-chip)
C_DC_IN | 10uF | C0805 | TBD
C_DC_OUT | 10uF | C0805 | TBD
C_VM | 10uF | C0805 | TBD
D1 | SS34 | SMA | C8678
L1 | 33uH power inductor 1.5A DJNR6045-330 | 6045 (6x6x4.5mm)
LED1 | LED green | 0805 | TBD
LED2 | LED blue | 0805 | TBD

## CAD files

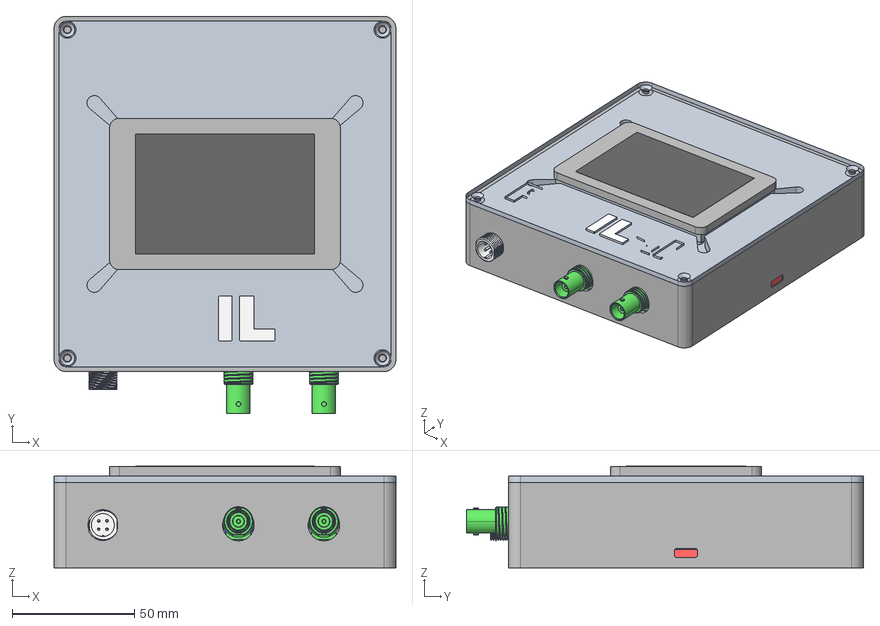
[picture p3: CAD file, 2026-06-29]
designs/full_assembly_v7.step
140.0 x 162.7 x 41.6 mm
EDGE x 111
WIRE

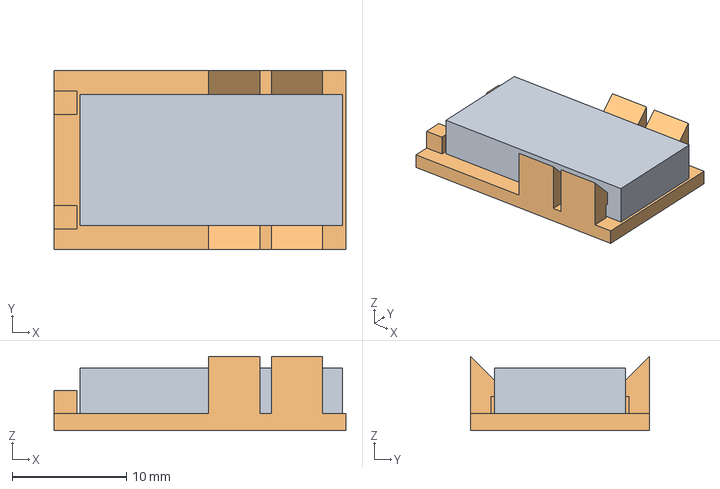
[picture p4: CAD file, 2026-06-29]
designs/ctp09_debug.step
25.6 x 15.7 x 6.50 mm

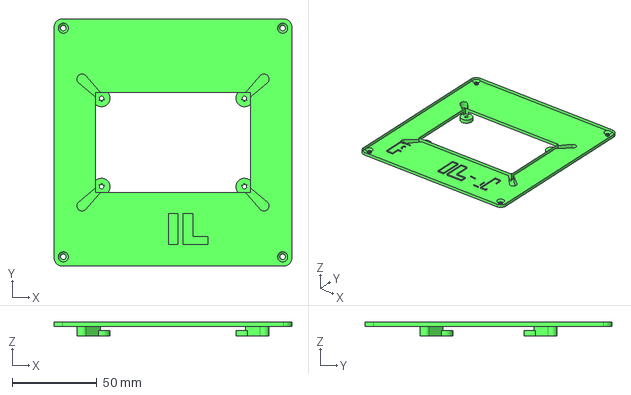
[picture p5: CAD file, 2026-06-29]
designs/lid.step
140.0 x 145.5 x 8.00 mm

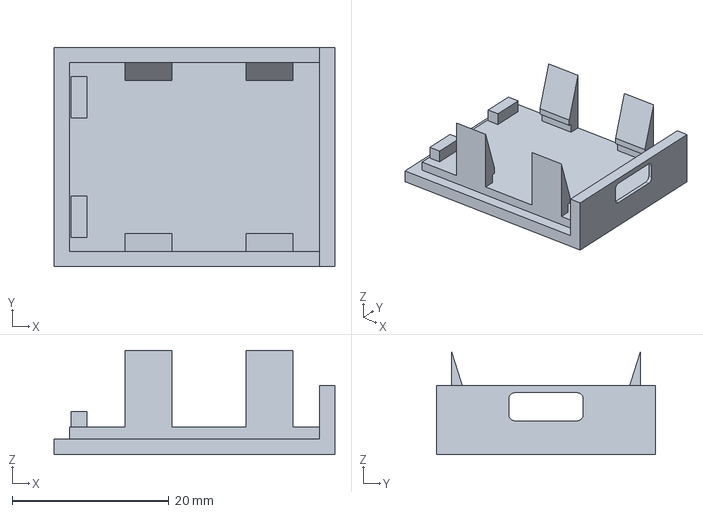
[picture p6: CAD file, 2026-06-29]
designs/ch224k_mount_test.step
35.9 x 28.0 x 13.3 mm

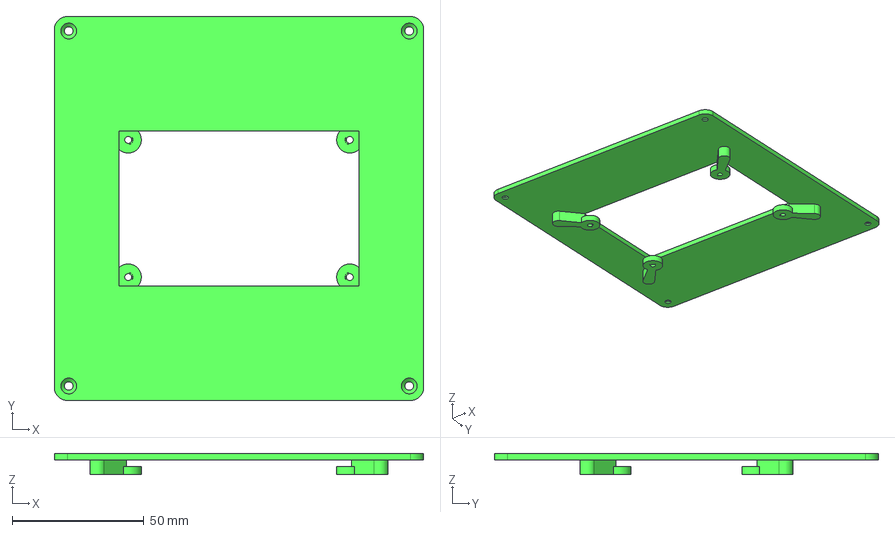
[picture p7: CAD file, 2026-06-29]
designs/lid_no_text.step
140.0 x 145.5 x 8.00 mm

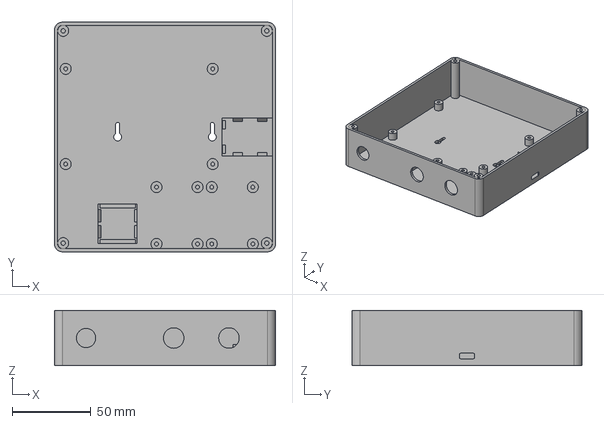
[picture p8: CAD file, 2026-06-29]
designs/case.step
140.0 x 145.5 x 35.0 mm

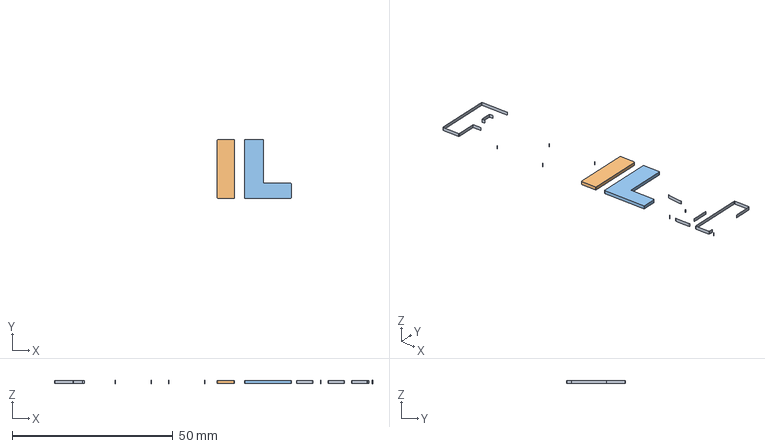
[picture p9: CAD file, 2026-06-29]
designs/lid_text.step
98.9 x 18.3 x 1.00 mm

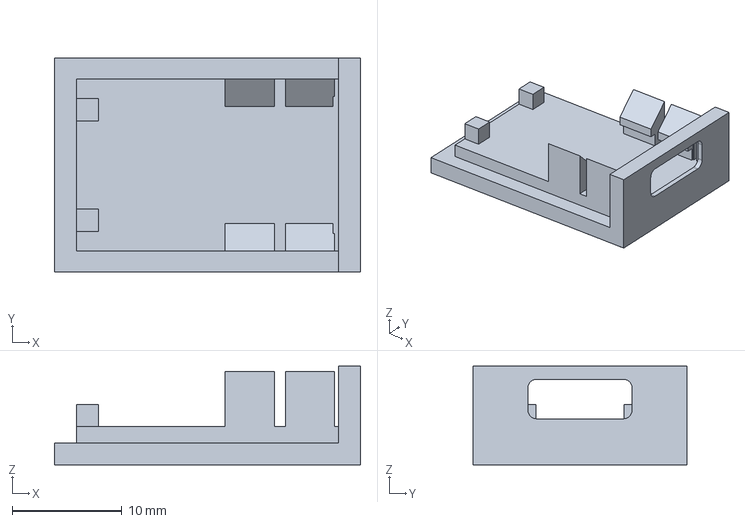
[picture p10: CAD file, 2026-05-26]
designs/ctp09_mount_test.step
27.9 x 19.5 x 9.00 mm

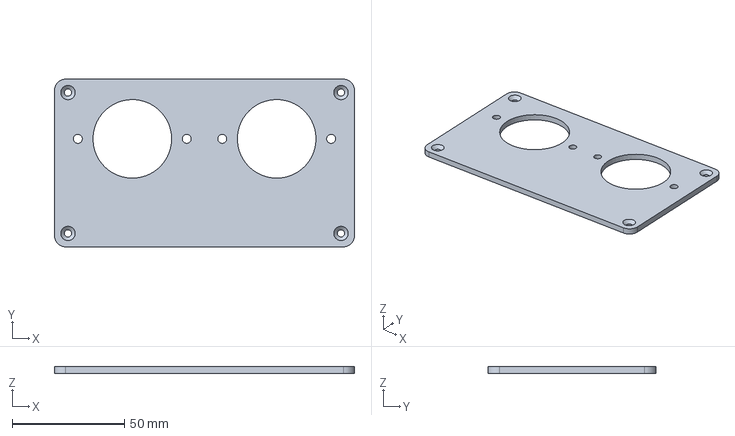
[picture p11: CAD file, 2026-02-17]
designs/pump_case_lid.step
133.6 x 74.7 x 3.00 mm

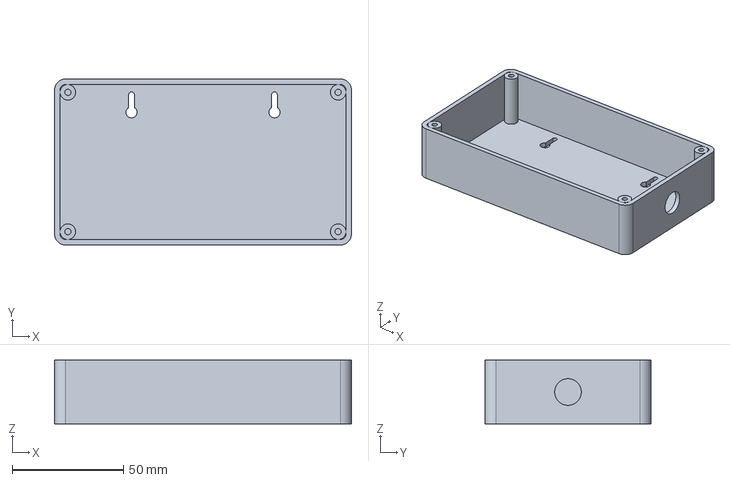
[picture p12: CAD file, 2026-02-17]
designs/pump_case_bucket.step
133.6 x 74.7 x 28.8 mm

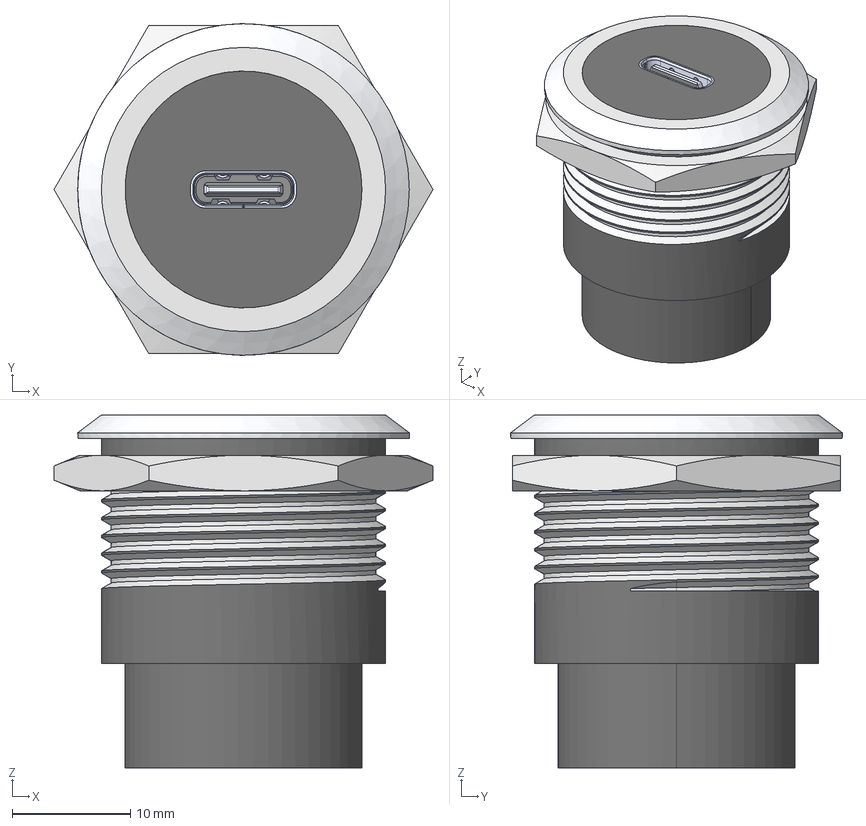
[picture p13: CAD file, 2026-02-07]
designs/USB-C.stp
32.0 x 28.0 x 29.8 mm
connector 2
Connector 1

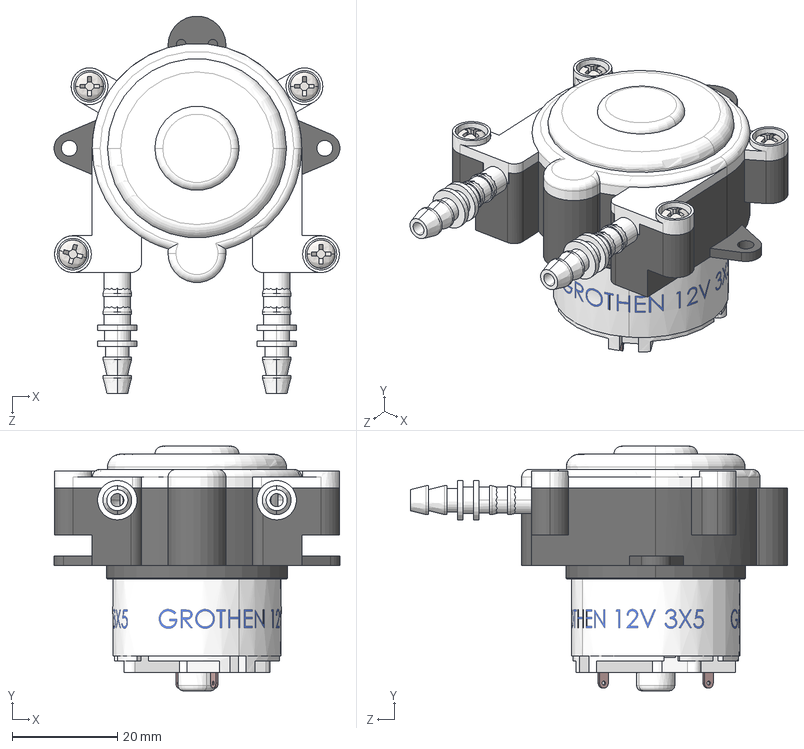
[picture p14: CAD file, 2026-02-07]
designs/Grothen-3x5-Peristaltic-Pump.STEP
54.3 x 46.5 x 71.7 mm
Pump case
12V DC engine
Lower roller holder
Roller x 3
Upper roller holder
Pump cover
Silicone tube 3x5mm
ISO7046 M2.5x5mm x 2
Tapping screw DIN 7049 ST2.9x9.5 x 4
Fitting x 2

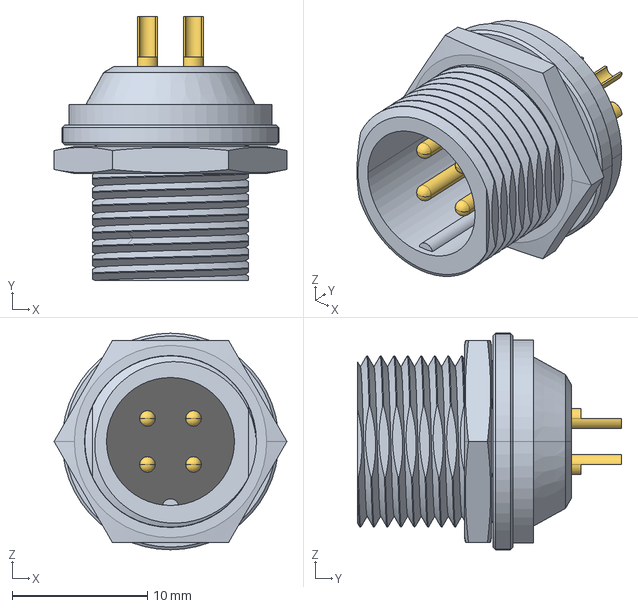
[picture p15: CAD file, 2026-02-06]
designs/gx12-4p-m.stp
17.2 x 19.5 x 16.0 mm

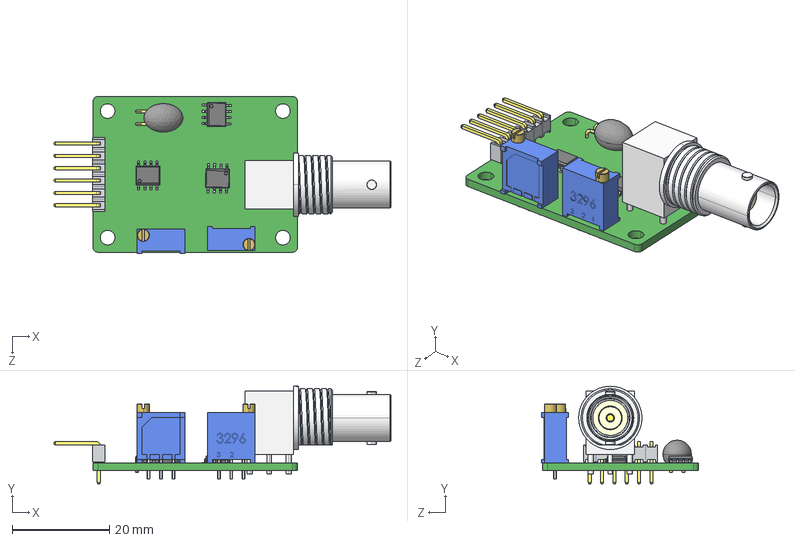
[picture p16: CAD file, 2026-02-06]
designs/PH-4502C.STEP
69.2 x 20.0 x 32.3 mm
Board_ph
BNC_90
Trimpot multivoltas_Valor predeterminado x 2
pin_header_6
S08.stp x 3
ptc

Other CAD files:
designs/TB6612.step
designs/LM2596.stp
designs/case.stl
designs/ch224k_mount_test.stl
designs/ctp09_mount_test.stl
designs/lid.stl
designs/lid_no_text.stl
designs/lid_text.stl
designs/pump_case_bucket.stl
designs/pump_case_lid.stl

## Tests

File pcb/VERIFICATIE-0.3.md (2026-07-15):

# Rev 0.3 — verificatierapport (vóór bestellen)

Alles hieronder is **tegen de datasheets** geverifieerd (PDF's in de sessie-scratchpad
gedownload van WCH/TI/Toshiba/ADI/Mornsun/Sumida/Panasonic), niet uit het hoofd.
Datum: juli 2026.

## 1. Import-footprints: pin-mapping vs datasheet

Elke pin van elke geïmporteerde footprint vergeleken met de pinout-tekening/pintabel
in de datasheet. **Alle 7 kloppen:**

| Import | Package | Datasheet-check | Resultaat |
|---|---|---|---|
| CH224K | ESSOP-10 | pinout-figuur §4.1: 1=VDD, 2=CFG2, 3=CFG3, 4=DP, 5=DM, 6=CC2, 7=CC1, 8=VBUS, **9=CFG1**, 10=PG, pad=GND | ✅ match — de 24k zit écht op CFG1 |
| LM2596S TO-263-5 | KTT | pintabel: 1=VIN, 2=Output, 3=Ground, 4=Feedback, 5=ON/OFF | ✅ match; pin5→GND = regelaar AAN (datasheet-sanctioned) |
| ADS1115 | VSSOP-10 | pintabel: 1=ADDR, 2=ALERT/RDY, 3=GND, 4–7=AIN0–3, 8=VDD, 9=SDA, 10=SCL | ✅ match |
| TB6612FNG | SSOP-24 | pintabel p.2: 1/2=AO1 … 24=VM1 | ✅ match |
| ADuM1250 | SOIC-8 | 1=VDD1, 2=SDA1, 3=SCL1, 4=GND1, 5=GND2, 6=SCL2, 7=SDA2, 8=VDD2 | ✅ match |
| B0505S-1WR3 | SIP-4 | pintabel p.6: **1=GND, 2=Vin, 3=0V, 4=+Vo** | ✅ match — input dus niet omgekeerd |
| USB-C 16P | TYPE-C-31-M-12 | padvolgorde A1B12·A4B9·B8·A5·B7·A6·A7·B6·A8·B5·B4A9·B1A12, 0.5 mm pitch | ✅ match met standaard 16-pins layout |

Noot CC-pinnen: J1.A5→U1.CC2 en J1.B5→U1.CC1 zijn "gekruist" — elektrisch irrelevant,
de CH224K doet orientation-detect (een omgedraaide kabel doet exact dezelfde swap).

## 2. Pin-coverage: elke chippin verbonden of bewust NC

| Chip | Verbonden | Bewust NC (met datasheet-reden) |
|---|---|---|
| U1 CH224K | VDD (via 1k), VBUS (via 10k), CC1/CC2, CFG1 (24k), DP–DM kortgesloten, GND | CFG2/CFG3 (interne pull-down, single-resistor-config §6.1), PG (open-drain, optioneel) |
| U2 LM2596 | VIN, OUT, GND, FB, ON/OFF→GND (=aan), EP→GND | — |
| U3 ADS1115 | ADDR→0R→AGND (0x48), AIN0/1, VDD, GND, SDA, SCL | ALERT/RDY + AIN2/3: §9.1.4 "float unused analog inputs" ✔ |
| U4 TB6612 | alle inputs, VCC=3V3, STBY→VCC, VM1/2/3=12V, GND, PGND11/21, AO11/AO21/BO11/BO21 | AO12/22, BO12/22, PGND12/22 — gepaarde pinnen zitten per blokdiagram op **dezelfde interne node**; enkele pin volstaat bij ~0,3 A pompen (paar pas nodig richting 1 A+) |
| U5 B0505S | alle 4 | — |
| U6 ADuM1250 | alle 8 | — |
| J1 USB-C | VBUS ×2, GND ×2, CC ×2, shell EH1/EH2→GND | D±/SBU: PD-only per CH224K §5.5 (DP/DM juist NIET aan connector) |

Polariteit elco's: C_IN pin1(+)→12V, C_OUT pin1(+)→5V, beide pin2→GND ✅.

## 3. Fouten gevonden en gefixt in deze verificatieronde

| # | Fout | Impact | Fix |
|---|---|---|---|
| 1 | **AGND-eiland dekte de 0.3-plaatsing niet meer**: 7 van de 10 AGND-pads lagen buiten de (uit rev 0.2 geporte) polygon | iso-domein zonder AGND-koper; router had het "opgelost" met sporen dwars door het GND-domein → isolatiebarrière lek | nieuwe eiland-polygon in `port_zones.py` (`ISLAND_PTS_03`), 10/10 pads binnen, fill geverifieerd binnen de contour |
| 2 | **tsci-export genereert eigen prio-0 zones**, incl. een AGND-zone over het héle board met kopervlekjes búiten het eiland | AGND-koper buiten de isolatiebarrière | `port_zones.py` verwijdert nu álle bestaande zones vóór het plaatsen van de 3 hand-zones |
| 3 | **BOM-MPN's EEE-1EA101P / EEE-1CA221P zijn Ø8×10.2 (case F)**, niet Ø6.3 | elco's zouden niet op de getekende Ø6.3-lands passen | BOM → **EEE-1EA101XP / EEE-1CA221XP** (case D8, 6.3×7.7). ⚠️ Meet de al via Ali bestelde 100 µF: moet Ø6.3 zijn |
| 4 | **L1-land te smal**: getekend 2.0×2.6-pads, maar Sumida CD54 vraagt pads van 2.15×**5.5** (de voetjes zijn 5.2 mm breed), gap 1.7 | pads dekten <50% van de terminals: zwakke verbinding, scheeftrek-risico | tsx-footprint → 2×(2.15×5.5) op ±1.925, silk verruimd; export/DRC opnieuw gedraaid |
| 5 | SRR5028-330Y stond als TME-alternatief voor L1 | ander landpattern — past niet op het CD54-land | uit de BOM; CD54 is al via Ali besteld |

Land C_IN/C_OUT geverifieerd tegen Panasonic "Recommended land Pattern": D/D8 = a 1.8 / b 3.2 / c 1.6.
Getekend: pads 3.2 lang, gap 2.0 — terminal (binnenrand op 1,5 mm van hart) valt volledig op de pad ✅.

## 4. Status board-bestand

`pura-mainboard-0805-0.3.kicad/` is opnieuw geëxporteerd (na de L1-fix), zones geport
(nieuw eiland), gevuld en headless door DRC gehaald:

- 68 unconnected (verwacht: board is nog niet geroute)
- 4× starved_thermal → bekende instelling: Board Setup → Constraints → **min thermal spoke count 2→1**
- rest = silk/text/lib-cosmetica

## 5. Rest-risico's (klein, expliciet benoemd)

1. **Ali-onderdelen fysiek meten vóór solderen**: de 100 µF elco (Ø6.3?), de CD54 (voetjes 5.2 breed?), de USB-C (16P TYPE-C-31-M-12 — leg 'm op een print van de gerber 1:1).
2. **CH224K-kloon-kwaliteit** van Ali is niet te verifiëren op papier; de bring-up-stap "eerst VBUS=12V meten vóór de rest aansluiten" (PRODUCTIE.md §7) vangt dit af.
3. **Placement-kwaliteit** (geen fout, wel suboptimaal): C_ISO2 zit ~10 mm van U6 en C_DC_OUT ~7 mm van U5; decoupling werkt het best <3 mm. Functioneel prima op 100 kHz-I²C, maar als je toch schuift in KiCad: deze twee dichterbij.
4. De AIN-sporen (pH/ORP, hoogohmig) lopen straks door de eiland-gang onderlangs, langs J_M1/J_M2 (motoruitgangen). Route de motorsporen aan de bovenkant van de connectors, niet door de gang.

## 6. Go/no-go

**GO** voor bestellen — ná deze twee handmatige checks:
- [ ] gemeten: Ali-elco 100 µF is Ø6.3 (anders EEE-1EA101XP bij TME meebestellen)
- [ ] freerouting gedaan → refill (B) → DRC 0 echte fouten → gerbers

Schema voor eigen review: `pura-0.3-schema.svg`.

---

# Eindcontrole vóór bestellen (juli 2026, 2e ronde)

Volledige her-verificatie op het definitieve board. **Geen board-killende fouten.**

## Geverifieerd OK

| Check | Resultaat |
|---|---|
| DRC | 0 unconnected, 0 shorts, 0 clearance, 0 schematic-parity |
| Netlist | 102 traces, alles verbonden |
| Polariteit | D1/C_IN/C_OUT/LED1/LED2 geverifieerd tegen tscircuit's **eigen port-hints** (pin1=anode/pos). Catch-diode: anode→GND, kathode→switchnode = correct |
| Stroomcapaciteit | 0.6mm = 1,64A (IPC-2221, 1oz, 10°C rise); zwaarste net 12V ≈ 0,85A |
| Maakbaarheid JLC | sporen 0.2/0.25/0.6 (min 0.127) · via's 0.6/0.3 + 0.8/0.4, annular 0.15/0.20 (min 0.13) · boringen 0.7–1.0 (min 0.3) |
| Mechanisch | geen lijf-overlaps; L1↔C_OUT 0,55mm |
| Board | 50 × 50 mm |

## Gefixt in deze ronde

- **Silkscreen-polariteit** toegevoegd (was er niet — handsoldeer-risico): `+` bij C_IN/C_OUT/LED1/LED2 pin1, `K` bij D1's kathode. Posities gescand op >0.5mm vrije ruimte en geverifieerd dat elke markering het dichtst bij de júiste pin staat.
- **Versienummer** `Pura v0.3` op de silk.

## Bewust geaccepteerd (geen fout, wél een compromis)

**Isolatiekloof is 0,2 mm** tussen het GND- en AGND-domein (B0505S levert 1,5kV, ADuM1250 2,5kV). 12 primaire pads liggen binnen het AGND-eiland (o.a. U6's ESP-zijde, U5's ingang, R_SDA2/R_SCL2, J_12V) en er loopt 279mm GND-koper doorheen. De oorzaak is de plaatsing, die de domeinen verweeft.

**Bewust geaccepteerd**: het hele board is SELV (max 12V, USB-PD gevoed) — er is nergens hoogspanning. De hoofdfunctie van de isolatie (aardlus richting het zwembadwater verbreken, zodat de hoogohmige pH-meting klopt) wérkt: de DC-scheiding is intact. Wat je inlevert is robuustheid tegen zeldzame surge-/foutscenario's. Wil je dat alsnog: dan moet de plaatsing van de onderste boardhelft herzien worden zodat de barrière als schone lijn ónder U5/U6 loopt, met ≥1,5mm koper-vrije band.

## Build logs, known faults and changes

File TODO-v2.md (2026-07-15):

# Pura v2.0 — TODO

Changes queued for the next PCB + firmware revision. Do NOT touch until
v1.0 is assembled, flashed, and validated in a real pool.

## PCB (`pcb/pura-mainboard-noroute.tsx` + `.kicad_pcb`)

- **J_PROBE header**: 4-pin → 6-pin
  - Current: `V5_ISO, AGND, PH_PO, ORP_PO`
  - v2.0: `V5_ISO, AGND, PH_PO, ORP_PO, TDS_PO, TURB_PO`
- Route ADS1115 `AIN2` → J_PROBE.TDS_PO
- Route ADS1115 `AIN3` → J_PROBE.TURB_PO
- Bump revision label on silkscreen: `v1.0` → `v2.0`
- Re-export gerbers + BOM + CPL (BOM unchanged, CPL only if header footprint moves)

## Firmware — new sensors

- Rename `AdsPhOrpSensor` → `AdsPoolSensor` (4 channels)
- Add telemetry fields: `float tdsPpm; float turbNtu; bool haveTds; bool haveTurb;`
- Storage: `getTdsFactor(0.5f)`, `getTurbZeroVolts(2.5f)` + setters
- `/settings` page: new **💧 Water Quality Sensors** section with calibration inputs
- WebUI `/`: add 2 metric cards (TDS ppm, TURB NTU) — grid stays 3-cols on desktop but wraps on mobile
- MQTT / Home Assistant: publish `pura/{id}/tds` and `pura/{id}/turb`
- Alert banners:
  - TDS > 600 ppm → "Water verdunnen (verversen)"
  - TURB > 10 NTU → "Algencheck — filter draaien, chloor-boost"

## Sensor hardware to source

- **TDS**: DFRobot Gravity Analog TDS Sensor (SEN0244) — ~€10
  - Output: 0-2.3V analog, 5V input
  - Range: 0-1000 ppm
- **TURB**: DFRobot Gravity Turbidity Sensor (SEN0189) — ~€8
  - Output: 0-4.5V analog, 5V input
  - Range: 0-3000 NTU

Both draw ~40mA @ 5V — well within B0505S iso-supply capacity.

## Things to double-check before v2.0

- v1.0 real-world validation: does the ADuM1250 + B0505S isolation actually
  eliminate the pool-water ground loop?
- Is 6-pin J_PROBE ergonomically OK, or split into 2× 3-pin?
- Do we want the CYA-reminder UI feature (manual monthly test tracking)?
- LM2596 thermal check under full load (all 4 sensors + motors + WiFi)

## Optional v2.0 nice-to-haves

- Salinity mode: reuse TDS sensor, different scaling factor
- 5V_ISO current limit / short protection (polyfuse or discrete)
- Better silkscreen: net names on pin headers (VBUS, GND, SDA etc.)
- Solder-jumper for `I2C_ADDR` on ADS (currently fixed via R_ADDR)

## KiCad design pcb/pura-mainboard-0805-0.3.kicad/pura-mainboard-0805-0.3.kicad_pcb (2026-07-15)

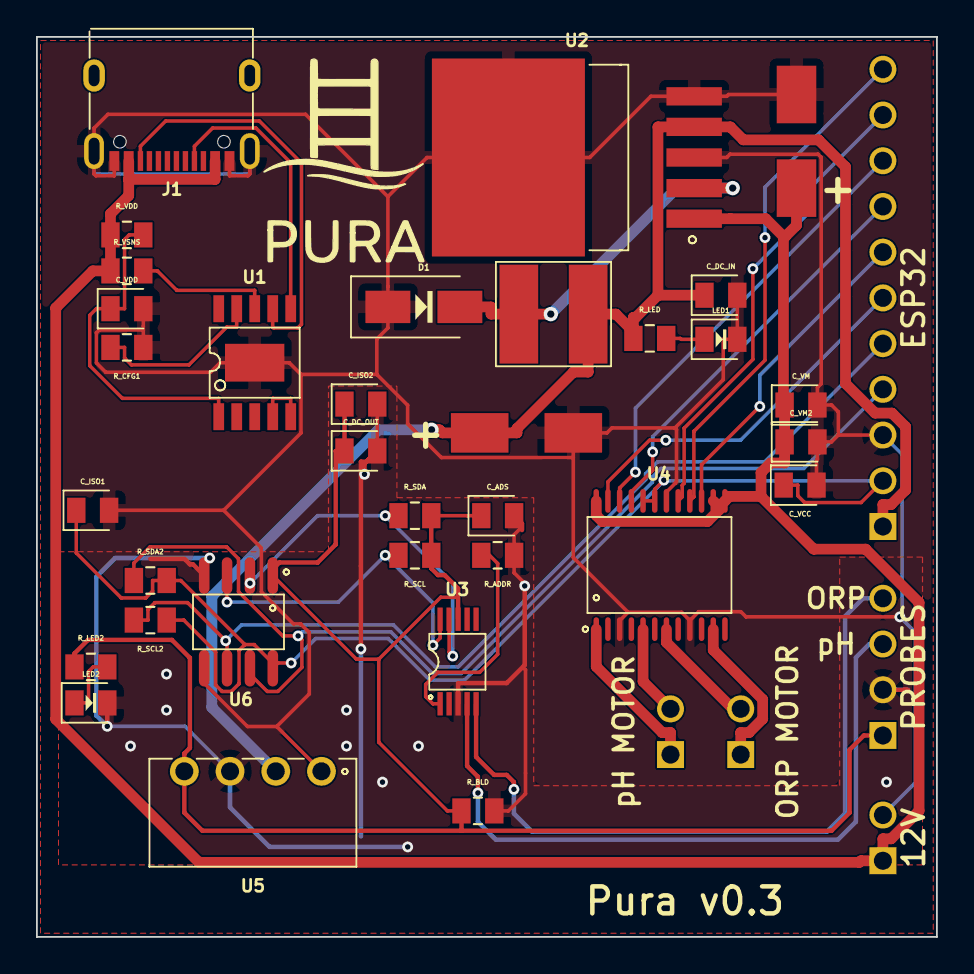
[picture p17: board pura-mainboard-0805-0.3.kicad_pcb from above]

Board: 2 copper layers, 50.0 x 50.0 mm, 38 parts (0 on the bottom side), 32 nets.

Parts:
C_ADS: 100nF; capacitor_0805
C_DC_IN: 10uF; capacitor_0805
C_DC_OUT: 10uF; capacitor_0805
C_IN: 100uF; capacitor
C_ISO1, C_ISO2: 100nF; capacitor_0805
C_OUT: 220uF; capacitor
C_VCC: 100nF; capacitor_0805
C_VDD: 1uF; capacitor_0805
C_VM: 10uF; capacitor_0805
C_VM2: 100nF; capacitor_0805
D1: D; SS34
J1: TYPE_C_16PIN_2MD_073_; TYPE_C_16PIN_2MD_073
J_12V: J_12V; pin_header_pinrow2_nopinlabels
J_ESP: J_ESP; pin_header_pinrow11_nopinlabels
J_M1: J_M1; pin_header_pinrow2_nopinlabels
J_M2: J_M2; pin_header_pinrow2_nopinlabels
J_PROBE: J_PROBE; pin_header_pinrow4_nopinlabels
L1: 33H; inductor
LED1: LED; led_0805_color(green)
LED2: LED; led_0805_color(cyan)
R_ADDR: 0Ω; resistor_res0805
R_BLD: 330Ω; resistor_res0805
R_CFG1: 24kΩ; resistor_res0805
R_LED, R_LED2: 2.2kΩ; resistor_res0805
R_SCL, R_SCL2: 4.7kΩ; resistor_res0805
R_SDA, R_SDA2: 4.7kΩ; resistor_res0805
R_VDD: 1kΩ; resistor_res0805
R_VSNS: 10kΩ; resistor_res0805
U1: CH224K
U2: LM2596S_5_0_UMW_; LM2596S_5_0_UMW
U3: ADS1115IDGST
U4: TB6612FNG_C_8_EL
U5: B0505S_1WR3
U6: ADUM1250ARZ_RL7

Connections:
.J1 > .A4B9 to .R_VDD > .pin1: C_IN.1, C_VM.1, C_VM2.1, J1.18, J1.27, J_12V.1, R_VDD.1, R_VSNS.1, U2.1, U4.13, U4.14, U4.24
.J1 > .A5 to .U1 > .CC2: J1.20, U1.6
.J1 > .B5 to .U1 > .CC1: J1.26, U1.7
.J_ESP > .SCL to .U6 > .SCL2: J_ESP.5, R_SCL2.1, U6.6
.J_ESP > .SDA to .U6 > .SDA2: J_ESP.4, R_SDA2.1, U6.7
.J_ESP > .V33 to .U4 > .VCC: C_ISO1.1, C_VCC.1, J_ESP.2, R_SCL2.2, R_SDA2.2, U4.19, U4.20, U6.8
.L1 > .pin2 to .U2 > .FB: C_DC_IN.1, C_OUT.1, J_ESP.1, L1.2, R_LED.1, U2.4, U5.2
.R_LED2 > .pin2 to .LED2 > .pin1: LED2.1, R_LED2.2
.R_LED > .pin2 to .LED1 > .pin1: LED1.1, R_LED.2
.R_VDD > .pin2 to .U1 > .VDD: C_VDD.1, R_VDD.2, U1.1
.R_VSNS > .pin2 to .U1 > .VBUS: R_VSNS.2, U1.8
.U1 > .CFG1 to .R_CFG1 > .pin1: R_CFG1.1, U1.9
.U1 > .DP to .U1 > .DM: U1.4, U1.5
.U2 > .OUT to .L1 > .pin1: D1.2, L1.1, U2.2
.U3 > .ADDR to .R_ADDR > .pin1: R_ADDR.1, U3.1
.U3 > .AIN0 to .J_PROBE > .PH_PO: J_PROBE.3, U3.4
.U3 > .AIN1 to .J_PROBE > .ORP_PO: J_PROBE.4, U3.5
.U3 > .SCL to .R_SCL > .pin1: R_SCL.1, U3.10, U6.3
.U3 > .SDA to .R_SDA > .pin1: R_SDA.1, U3.9, U6.2
.U4 > .AIN1 to .J_ESP > .AIN1: J_ESP.8, U4.21
.U4 > .AIN2 to .J_ESP > .AIN2: J_ESP.9, U4.22
.U4 > .AO11 to .J_M1 > .MA1: J_M1.1, U4.1
.U4 > .AO21 to .J_M1 > .MA2: J_M1.2, U4.5
.U4 > .BIN1 to .J_ESP > .BIN1: J_ESP.10, U4.17
.U4 > .BIN2 to .J_ESP > .BIN2: J_ESP.11, U4.16
.U4 > .BO11 to .J_M2 > .MB1: J_M2.1, U4.11
.U4 > .BO21 to .J_M2 > .MB2: J_M2.2, U4.7
.U4 > .PWMA to .J_ESP > .PWMA: J_ESP.6, U4.23
.U4 > .PWMB to .J_ESP > .PWMB: J_ESP.7, U4.15
.U5 > .pin4 to .U6 > .VDD1: C_ADS.1, C_DC_OUT.1, C_ISO2.1, J_PROBE.1, R_BLD.1, R_LED2.1, R_SCL.2, R_SDA.2, U3.8, U5.4, U6.1
AGND: C_ADS.2, C_DC_OUT.2, C_ISO2.2, J_PROBE.2, LED2.2, R_ADDR.2, R_BLD.2, U3.3, U5.3, U6.4
GND: C_DC_IN.2, C_IN.2, C_ISO1.2, C_OUT.2, C_VCC.2, C_VDD.2, C_VM.2, C_VM2.2, D1.1, J1.13, J1.14, J1.17, J1.28, J_12V.2, J_ESP.3, LED1.2, R_CFG1.2, U1.11, U2.3, U2.5, U2.6, U4.3, U4.9, U4.18, U5.1, U6.5

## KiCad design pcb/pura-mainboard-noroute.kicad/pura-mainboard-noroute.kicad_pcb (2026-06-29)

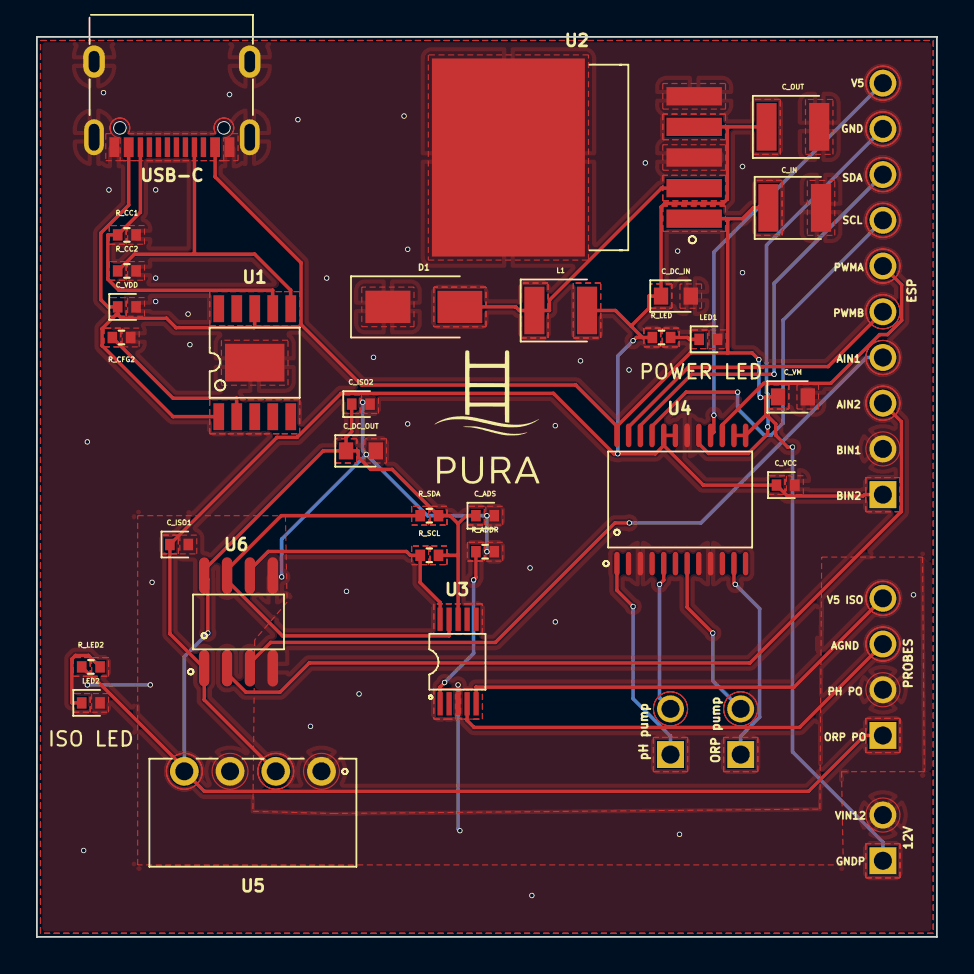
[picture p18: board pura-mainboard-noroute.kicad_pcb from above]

Board: 2 copper layers, 50.0 x 50.0 mm, 34 parts (0 on the bottom side), 28 nets.

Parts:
12V: J_12V; pin_header_pinrow2_nopinlabels
C_ADS: 100nF; capacitor_0402
C_DC_IN: 10uF; capacitor_0603
C_DC_OUT: 10uF; capacitor_0603
C_IN: 220uF; capacitor_1210
C_ISO1, C_ISO2: 100nF; capacitor_0402
C_OUT: 220uF; capacitor_1210
C_VCC: 100nF; capacitor_0402
C_VDD: 100nF; capacitor_0402
C_VM: 10uF; capacitor_0603
D1: D; SS34
ESP: J_ESP; pin_header_pinrow10_nopinlabels
L1: 33H; inductor_1210
LED1: LED; led_0402_color(green)
LED2: LED; led_0402_color(cyan)
MOTOR 1: J_M1; pin_header_pinrow2_nopinlabels
ORP pump: J_M2; pin_header_pinrow2_nopinlabels
PROBES: J_PROBE; pin_header_pinrow4_nopinlabels
R_ADDR: 0Ω; resistor_res0402
R_CC1, R_CC2: 5.1kΩ; resistor_res0402
R_CFG2: 0Ω; resistor_res0402
R_LED, R_LED2: 2.2kΩ; resistor_res0402
R_SCL: 4.7kΩ; resistor_res0402
R_SDA: 4.7kΩ; resistor_res0402
U1: CH224K
U2: LM2596S_5_0_UMW_; LM2596S_5_0_UMW
U3: ADS1115IDGST
U4: TB6612FNG_C_8_EL
U5: B0505S_1WR3
U6: ADUM1250ARZ_RL7
USB-C: TYPE_C_16PIN_2MD_073_; TYPE_C_16PIN_2MD_073

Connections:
.J1 > .A5 to .U1 > .CC2: R_CC2.1, U1.6, USB-C.20
.J1 > .B5 to .U1 > .CC1: R_CC1.1, U1.7, USB-C.26
.J_ESP > .SCL to .U6 > .SCL1: ESP.4, U6.3
.J_ESP > .SDA to .U6 > .SDA1: ESP.3, U6.2
.L1 > .pin2 to .U2 > .FB: C_DC_IN.1, C_ISO1.1, C_OUT.1, C_VCC.1, ESP.1, L1.2, R_LED.1, U2.4, U4.19, U4.20, U5.2, U6.1
.R_LED2 > .pin2 to .LED2 > .pin1: LED2.1, R_LED2.2
.R_LED > .pin2 to .LED1 > .pin1: LED1.1, R_LED.2
.U1 > .CFG2 to .R_CFG2 > .pin1: R_CFG2.1, U1.2
.U1 > .VDD to .U1 > .VBUS: 12V.1, C_IN.1, C_VDD.1, C_VM.1, U1.1, U1.8, U2.1, U4.13, U4.14, U4.24, USB-C.18, USB-C.27
.U2 > .OUT to .L1 > .pin1: D1.2, L1.1, U2.2
.U3 > .ADDR to .R_ADDR > .pin1: R_ADDR.1, U3.1
.U3 > .AIN0 to .J_PROBE > .PH_PO: PROBES.3, U3.4
.U3 > .AIN1 to .J_PROBE > .ORP_PO: PROBES.4, U3.5
.U3 > .SCL to .R_SCL > .pin1: R_SCL.1, U3.10, U6.6
.U3 > .SDA to .R_SDA > .pin1: R_SDA.1, U3.9, U6.7
.U4 > .AIN1 to .J_ESP > .AIN1: ESP.7, U4.21
.U4 > .AIN2 to .J_ESP > .AIN2: ESP.8, U4.22
.U4 > .AO11 to .J_M1 > .MA1: MOTOR 1.1, U4.1
.U4 > .AO21 to .J_M1 > .MA2: MOTOR 1.2, U4.5
.U4 > .BIN1 to .J_ESP > .BIN1: ESP.9, U4.17
.U4 > .BIN2 to .J_ESP > .BIN2: ESP.10, U4.16
.U4 > .BO11 to .J_M2 > .MB1: ORP pump.1, U4.11
.U4 > .BO21 to .J_M2 > .MB2: ORP pump.2, U4.7
.U4 > .PWMA to .J_ESP > .PWMA: ESP.5, U4.23
.U4 > .PWMB to .J_ESP > .PWMB: ESP.6, U4.15
.U5 > .pin4 to .U6 > .VDD2: C_ADS.1, C_DC_OUT.1, C_ISO2.1, PROBES.1, R_LED2.1, R_SCL.2, R_SDA.2, U3.8, U5.4, U6.8
AGND: C_ADS.2, C_DC_OUT.2, C_ISO2.2, LED2.2, PROBES.2, R_ADDR.2, U3.3, U5.3, U6.5
GND: 12V.2, C_DC_IN.2, C_IN.2, C_ISO1.2, C_OUT.2, C_VCC.2, C_VDD.2, C_VM.2, D1.1, ESP.2, LED1.2, R_CC1.2, R_CC2.2, R_CFG2.2, U1.11, U2.3, U2.5, U2.6, U4.3, U4.9, U4.18, U5.1, U6.4, USB-C.13, USB-C.14, USB-C.15, USB-C.16, USB-C.17, USB-C.28

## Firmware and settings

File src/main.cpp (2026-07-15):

// Pura — ESP32 pool monitor (pH, ORP, temp) with LVGL UI, MQTT, motors

#include <Arduino.h>
#include "driver/ledc.h"
#include <stdio.h>
#include <stdarg.h>
#include <HardwareSerial.h>
#include <SPI.h>
#include <vector>
#include <lvgl.h>
#include <WiFi.h>
#include <ArduinoOTA.h>
#include <PubSubClient.h>
#include <Preferences.h>
#include <esp_log.h>
#include <SPIFFS.h>
#include <FS.h>
#include "domain/DummySensor.h"
#include "domain/Telemetry.h"
// Board-specific display/touch/BSP includes are in core/boards/ implementations

// Board-agnostic LVGL locking — delegates to the active Board implementation
#define LVGL_LOCK()   getBoard().lvglLock()
#define LVGL_UNLOCK() getBoard().lvglUnlock()
#ifndef ZB_ENABLED
#if defined(BOARD_ESP32P4_43)
// P4: No native Zigbee, uses C6 bridge
#define ZB_ENABLED 0
#elif ((defined(FORCE_ZIGBEE) && FORCE_ZIGBEE) || (defined(HAS_ZIGBEE) && HAS_ZIGBEE)) && __has_include(<Zigbee.h>)
#define ZB_ENABLED 1
#else
#define ZB_ENABLED 0
#endif
#endif
static bool wifiOff = false;
static volatile bool g_settingsRequested = false;
static volatile bool g_startPortalRequested = false;
static volatile bool g_ui_ip_dirty = false;
static char g_ui_ip_buf[24] = {0};  // Thread-safe fixed buffer for IP text (replaces String)
static volatile bool g_showMainRequested = false;

extern "C" void requestShowMain(){ g_showMainRequested = true; }
// Global boot timestamp for UI grace periods
static uint32_t APP_BOOT_MS = 0;

// Core modules
#include "core/Storage.h"
#include "core/Board.h"
#include "domain/Metrics.h"
#include "domain/History.h"
#include "domain/ControlPolicy.h"
// IO modules
#include "io/MqttClient.h"
#include "io/Touch.h"
#include "io/AnalogPhOrpSensor.h"
#include "io/AdsPhOrpSensor.h"
#include "io/ZigbeeClient.h"
#include "io/CaptivePortal.h"
#include "io/PowerManager.h"
#include "io/Speaker.h"
#include "ui/UI.h"
// Provide C-linkage declarations for image assets used by UI when included here
extern "C" {
  extern const lv_img_dsc_t water_ph_32dp_E3E3E3_FILL0_wght400_GRAD0_opsz40;
  extern const lv_img_dsc_t water_orp_32dp_E3E3E3_FILL0_wght400_GRAD0_opsz40;
}
#include "io/WebUI.h"
#include "io/WiFiManager.h"
#include "boards/BoardSelect.h"
#include "io/Buttons.h"
#include "io/MotorController.h"
#include <HTTPClient.h>  // For WhatsApp CallMeBot notifications
// Icons
extern "C" const lv_img_dsc_t water_pump_24dp_E3E3E3_FILL0_wght400_GRAD0_opsz24;
extern "C" const lv_img_dsc_t water_ph_32dp_E3E3E3_FILL0_wght400_GRAD0_opsz40;
extern "C" const lv_img_dsc_t water_orp_32dp_E3E3E3_FILL0_wght400_GRAD0_opsz40;
extern "C" const lv_img_dsc_t link_32dp_E3E3E3_FILL0_wght400_GRAD0_opsz40;
extern "C" const lv_img_dsc_t link_off_32dp_E3E3E3_FILL0_wght400_GRAD0_opsz40;
extern "C" const lv_img_dsc_t link_16dp_999999_FILL0_wght400_GRAD0_opsz20;
extern "C" const lv_img_dsc_t link_off_16dp_999999_FILL0_wght400_GRAD0_opsz20;

#define FIRMWARE_VERSION __DATE__ " " __TIME__

// Local convenience accessor for metrics (scoped to this file only)
static inline domain::Metrics& METRICS(){ return domain::Metrics::instance(); }
extern "C" const lv_font_t lv_font_source_code_pro_16;
extern "C" const lv_font_t lv_font_montserrat_14;
extern "C" const lv_font_t lv_font_source_code_pro_18;
extern "C" const lv_font_t lv_font_source_code_pro_36;
extern "C" const lv_font_t lv_font_source_code_pro_36_bold;
#include "core/Log.h"
// ====== USER CONFIG ======
// Set to true for a minimal diagnostic mode (serial prints + color flashes)
static const bool DIAG_MODE = false;
// Board pins snapshot — populated in setup() from getBoard().pins()
static core::BoardPins g_pins;

// ===== Analog sensor (PH4502C/ORP) integration =====
// Enable to read pH and ORP from two ADC pins (PH-4502C / ORP-4502C boards)
#ifndef USE_ANALOG_SENSORS
#define USE_ANALOG_SENSORS 0
#endif
#ifndef USE_ADS1115
#define USE_ADS1115 0
#endif
#if USE_ANALOG_SENSORS
  // Define ADC-capable GPIOs here (set to actual free ADC pins on your board)
  #ifndef PH_ADC_PIN
  #define PH_ADC_PIN -1
  #endif
  #ifndef ORP_ADC_PIN
  #define ORP_ADC_PIN -1
  #endif
  io::AnalogPhOrpSensor g_analog(PH_ADC_PIN, ORP_ADC_PIN);
  // Expose to UI namespace for calibration
  namespace ui { extern io::AnalogPhOrpSensor& g_analog; }
  io::AnalogPhOrpSensor& ui::g_analog = ::g_analog;
#endif
#if USE_ADS1115
  #ifndef ADS_ADDR
  #define ADS_ADDR 0x48
  #endif
  #ifndef ADS_SDA
  #define ADS_SDA 18
  #endif
  #ifndef ADS_SCL
  #define ADS_SCL 19
  #endif
  #ifndef ADS_CH_PH
  #define ADS_CH_PH 0
  #endif
  #ifndef ADS_CH_ORP
  #define ADS_CH_ORP 1
  #endif
  io::AdsPhOrpSensor g_ads(ADS_ADDR, ADS_SDA, ADS_SCL, ADS_CH_PH, ADS_CH_ORP, io::AdsPhOrpSensor::GAIN_2_3, 8, 1000);
#endif
#if USES_ARDUINO_GFX
static const bool USE_LVGL_UI = true;  // C6 & P4 use LVGL UI
#else
static const bool USE_LVGL_UI = true;  // S3: LVGL cards UI
#endif
// Safe rollback: keep LVGL minimal to avoid crashes while debugging
// On S3 with JC driver, start with safe baseline UI to avoid complex widgets until stable
#if defined(BOARD_ESP32S3_35) && defined(USE_JC3248W535)
static const bool LVGL_SAFE_BASELINE = false; // enable full UI on S3
#else
static const bool LVGL_SAFE_BASELINE = false;
#endif

// ===== LVGL UI globals =====
static lv_obj_t *lv_tv = nullptr;
static lv_obj_t *lv_tile_main = nullptr;
static lv_obj_t *lv_tile_settings = nullptr;
static lv_obj_t *lv_dots = nullptr;
// Card containers + titles
static lv_obj_t *lv_card_ph = nullptr;
static lv_obj_t *lv_card_orp = nullptr;
static lv_obj_t *lv_card_temp = nullptr;
static lv_obj_t *lv_lbl_ph_title = nullptr;
static lv_obj_t *lv_lbl_orp_title = nullptr;
static lv_obj_t *lv_lbl_temp_title = nullptr;
static volatile uint32_t lv_flush_count = 0;
static volatile uint32_t lv_touch_press_count = 0;
static volatile int16_t lv_touch_last_x = -1;
static volatile int16_t lv_touch_last_y = -1;
// Touch cache polled by a fast LVGL timer to avoid missing short taps

// Main page widgets
static lv_obj_t *lv_lbl_ph = nullptr;
static lv_obj_t *lv_lbl_orp = nullptr;
static lv_obj_t *lv_lbl_temp = nullptr;
static lv_obj_t *lv_lbl_orp_unit = nullptr;
static lv_obj_t *lv_lbl_ph_shadow = nullptr;
static lv_obj_t *lv_lbl_orp_shadow = nullptr;
static lv_obj_t *lv_img_ph_icon = nullptr;
static lv_obj_t *lv_img_orp_icon = nullptr;
static lv_obj_t *lv_img_pump_ph = nullptr;
static lv_obj_t *lv_img_pump_orp = nullptr;
static lv_obj_t *lv_img_ph_icon_shadow = nullptr;
static lv_obj_t *lv_img_orp_icon_shadow = nullptr;
static lv_obj_t *lv_img_pump_ph_shadow = nullptr;
static lv_obj_t *lv_img_pump_orp_shadow = nullptr;
static lv_obj_t *lv_lbl_pump_ph_stats = nullptr;   // Session volume + flow rate label
static lv_obj_t *lv_lbl_pump_orp_stats = nullptr;
static lv_obj_t *lv_lbl_ip = nullptr;
static lv_obj_t *lv_lbl_batt = nullptr;  // Battery level label
static lv_obj_t *lv_img_link = nullptr;
static lv_obj_t *lv_link_wrap = nullptr;
static lv_obj_t *lv_lbl_link_dbg = nullptr;
static lv_obj_t *lv_lbl_m1 = nullptr; // motor1 indicator
static lv_obj_t *lv_lbl_m2 = nullptr; // motor2 indicator
static lv_obj_t *lv_zb_modal = nullptr; // zigbee commissioning modal

// Settings widgets
static lv_obj_t *lv_lbl_speed1 = nullptr;
static lv_obj_t *lv_lbl_speed2 = nullptr;
static lv_obj_t *lv_sl_speed1 = nullptr;
static lv_obj_t *lv_sl_speed2 = nullptr;

// Forward declarations for LVGL helper functions (definitions are below metrics/globals)
static void lv_update_speed_labels();
static void on_ph_minus_cb(lv_event_t *e);
static void on_ph_plus_cb(lv_event_t *e);
static void on_orp_minus_cb(lv_event_t *e);
static void on_orp_plus_cb(lv_event_t *e);
static void on_all_off_cb(lv_event_t *e);
static void on_speed_save_cb(lv_event_t *e);
static void updateLvglValues();
static void showRangeEditorProxy(bool isPh);
// Enable dummy/test mode to generate values without the meter connected
#if USE_ANALOG_SENSORS || USE_ADS1115
static const bool DUMMY_MODE = false;  // sensors are connected
#else
static const bool DUMMY_MODE = true;   // simulate values
#endif
static domain::DummySensor g_dummySensor(6.80f, 7.60f, 250);
// Tap vs swipe detection for tiles
struct TileTapCtx { bool isPh; lv_point_t start; uint32_t start_ms; bool maybe_tap; };
static void tile_tap_cb(lv_event_t *e){
  TileTapCtx *ctx = (TileTapCtx*)lv_event_get_user_data(e);
  lv_event_code_t code = lv_event_get_code(e);
  if (!ctx) return;
  const int SLOP = 12; // px
  const uint32_t MAX_TAP_MS = 300;
  if (code == LV_EVENT_PRESSED) {
    lv_indev_t *indev = lv_indev_get_act();
    lv_point_t p; p.x = p.y = 0;
    if (indev) lv_indev_get_point(indev, &p);
    ctx->start = p; ctx->start_ms = lv_tick_get(); ctx->maybe_tap = true;
  } else if (code == LV_EVENT_PRESSING) {
    lv_indev_t *indev = lv_indev_get_act();
    lv_point_t p; p.x = p.y = 0;
    if (indev) lv_indev_get_point(indev, &p);
    int dx = LV_ABS(p.x - ctx->start.x);
    int dy = LV_ABS(p.y - ctx->start.y);
    if (dx > SLOP || dy > SLOP) ctx->maybe_tap = false; // it's a swipe/drag
  } else if (code == LV_EVENT_RELEASED) {
    if (ctx->maybe_tap && lv_tick_elaps(ctx->start_ms) <= MAX_TAP_MS) {
      showRangeEditorProxy(ctx->isPh);
    }
  }
}

// ---- TB6612FNG motor driver (optional dosing pumps) ----
static const bool MOTOR_ENABLE = true; // compile-time guard; runtime toggle via storage
static const bool MOTOR_TEST   = false; // jog both motors at boot to verify wiring
// Force Motor A continuously on (test). Set true for hard-on at 100% duty.
static const bool FORCE_MOTOR_A_ON = false;

// Motor pin aliases resolved from g_pins (populated in setup() via getBoard().pins()).
// Defined as references to g_pins fields for readable use at call sites.
#define TB_STBY (g_pins.motorStby)
#define M1_IN1  (g_pins.m1in1)
#define M1_IN2  (g_pins.m1in2)
#define M1_PWM  (g_pins.m1pwm)
#define M2_IN1  (g_pins.m2in1)
#define M2_IN2  (g_pins.m2in2)
#define M2_PWM  (g_pins.m2pwm)

// Control policy thresholds and timing
static float PH_MIN = 6.80f, PH_MAX = 7.60f;   // outside → run Motor1
static int   ORP_MIN = 250, ORP_MAX = 850;     // mV outside → run Motor2
static uint8_t  M1_SPEED_PC = 60;     // PWM duty % (pH)
static uint8_t  M2_SPEED_PC = 60;     // PWM duty % (ORP)
// Pump flow rates (ml/min at 100% speed) - default 50ml/min for 5x3mm tube
static float M1_FLOW_RATE = 50.0f;   // ml/min at 100% speed for Motor 1
static float M2_FLOW_RATE = 50.0f;   // ml/min at 100% speed for Motor 2

// Safety limits (loaded from storage, with sensible defaults)
static float MAX_DAILY_VOLUME = 500.0f;       // ml per day per pump (prevents runaway)
static float MAX_SESSION_VOLUME = 50.0f;      // ml per session (prevents single overdose)
static int MAX_SESSION_DURATION = 300;        // seconds (5 minutes max continuous run)
static float PH_SANITY_MIN = 4.0f;            // pH below this is sensor error
static float PH_SANITY_MAX = 10.0f;           // pH above this is sensor error
static int ORP_SANITY_MIN = -200;             // mV below this is sensor error
static int ORP_SANITY_MAX = 1200;             // mV above this is sensor error
static int SENSOR_TIMEOUT = 300;              // seconds without valid sensor data before stop

// WhatsApp notifications (CallMeBot API)
static String CALLMEBOT_API_KEY = "";             // Loaded from storage (NVS)
static String WHATSAPP_PHONE = "";             // +31... format (loaded from storage)
static bool WHATSAPP_ENABLED = false;          // Enable/disable notifications

// PWM setup (use Arduino analogWrite APIs for C6)
static const int PWM_FREQ = 6000; // 6 kHz (smoother for TB6612)
static const int PWM_BITS = 10;   // 0..1023 finer control

// Internal motor state
static bool m1Running = false, m2Running = false;
static bool emergencyStop = false; // when true, force both motors off until reboot or future clear
// Hysteresis for continuous control (no burst/cooldown)
static const float PH_HYST = 0.05f;   // stop when pH < (PH_MAX - PH_HYST)
static const int   ORP_HYST = 20;     // stop when ORP > (ORP_MIN + ORP_HYST)

// (helpers moved below prefs)

// (helpers moved below metrics and prefs)
// ---- WiFi + MQTT (Home Assistant via Mosquitto) ----
static String WIFI_SSID     = "";
static String WIFI_PASSWORD = "";
static String MQTT_HOST     = "192.168.0.248"; // default; overridden by storage
static uint16_t MQTT_PORT  = 1883;
static String MQTT_USER     = "";  // optional
static String MQTT_PASS     = "";  // optional
static char MQTT_CLIENTID_BUF[48] = {0};
static const char* MQTT_CLIENTID = MQTT_CLIENTID_BUF;
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
void loop() {
     // Audio Feedback (Offloaded from ISR/Timer context - GLOBAL)
    if (g_click_requested) {
        g_click_requested = false;
        if (g_storage.getSoundEnabled(true)) {
            speaker.beep();
        }
    }
    speaker.loop();

    if (USE_LVGL_UI) {
    delay(0);
    // Apply deferred UI IP update from WiFi callback without crossing threads
    if (g_ui_ip_dirty) {
      g_ui_ip_dirty = false;
      if (LVGL_LOCK()) { ui::setIp(g_ui_ip_buf); LVGL_UNLOCK(); }
    }
    updateLvglValues();
    if (!MOTOR_ENABLE) {
      bool phActive = METRICS().havePh && (METRICS().phVal < PH_MIN || METRICS().phVal > PH_MAX);
      bool orpActive = METRICS().haveOrp && ((int)lrintf(METRICS().orpMv) < ORP_MIN || (int)lrintf(METRICS().orpMv) > ORP_MAX);
      // Only toggle legacy main-UI icons on non-S3 routes; S3/JC uses module UI via ui::setPumpActive
      #if !defined(BOARD_ESP32S3_35)
      if (lv_img_pump_ph && lv_img_pump_ph_shadow) {
        if (phActive) { lv_obj_clear_flag(lv_img_pump_ph, LV_OBJ_FLAG_HIDDEN); lv_obj_clear_flag(lv_img_pump_ph_shadow, LV_OBJ_FLAG_HIDDEN); }
        else { lv_obj_add_flag(lv_img_pump_ph, LV_OBJ_FLAG_HIDDEN); lv_obj_add_flag(lv_img_pump_ph_shadow, LV_OBJ_FLAG_HIDDEN); }
      }
      if (lv_img_pump_orp && lv_img_pump_orp_shadow) {
        if (orpActive) { lv_obj_clear_flag(lv_img_pump_orp, LV_OBJ_FLAG_HIDDEN); lv_obj_clear_flag(lv_img_pump_orp_shadow, LV_OBJ_FLAG_HIDDEN); }
        else { lv_obj_add_flag(lv_img_pump_orp, LV_OBJ_FLAG_HIDDEN); lv_obj_add_flag(lv_img_pump_orp_shadow, LV_OBJ_FLAG_HIDDEN); }
      }
      #endif
      // Ensure module UI icons reflect threshold state too
      ui::setPumpActive(phActive, orpActive);
    }
  } else if (DIAG_MODE) {
    static uint32_t last = 0;
    uint32_t now = millis();
    if (now - last > 1000) {
      last = now;
      ESP_LOGI("DIAG", "millis=%u", (unsigned)now);
      // visual heartbeat (serial only — display objects are now board-local)
      static bool toggle = false; toggle = !toggle;
      ESP_LOGI("DIAG", "heartbeat %s", toggle ? "ON" : "OFF");
    }
    return;
  }
  // Apply deferred navigation back to main UI (one-shot)
  if (g_showMainRequested) {
    g_showMainRequested = false;
    // Always defer via zero-delay timer so showMain() runs in the LVGL context
    lv_timer_t *t = lv_timer_create([](lv_timer_t *tm){ (void)tm; ui::showMain(); }, 0, NULL);
    lv_timer_set_repeat_count(t, 1);
  }
  // Removed alive ticker

  // --- Button long-press detection for Zigbee commissioning ---
  if (g_buttons.pollLongPress(3000)) {
      ESP_LOGI("ZB", "Long press: start commissioning now (120s)");
    if (USE_LVGL_UI) ui::showHoldToPair();
    #if ZB_ENABLED
      savedMode = runMode;
      modeForced = true;
      runMode = core::Storage::MODE_ZIGBEE; g_storage.setMode(runMode);
      if (WiFi.isConnected()) WiFi.disconnect(true, true);
      WiFi.mode(WIFI_OFF);
      wifiOff = true;
      zigbee.startCommission(120);
#endif
    }

  // If commissioning finished, optionally restore WiFi
  #if ZB_ENABLED
  if (wifiOff && zigbee.isStarted() && zigbee.commissionUntilMs() && millis() > zigbee.commissionUntilMs()) {
    ESP_LOGI("ZB", "Commissioning window ended");
    zigbee.clearCommissionTimer();
    if (modeForced) {
      // Restore user's previous mode selection
      runMode = savedMode;
      g_storage.setMode(runMode);
      modeForced = false;
    }
    if (runMode == core::Storage::MODE_WIFI_MQTT) {
      ESP_LOGI("WiFi", "Restoring WiFi STA (WiFi/MQTT mode)");
      WiFi.mode(WIFI_STA);
      wifiOff = false;
      wifiMgr.ensureSta();
      ensureMqtt();
    } else {
      // Remain in Zigbee-only mode; keep WiFi fully off
      WiFi.mode(WIFI_OFF);
      wifiOff = true;
      ESP_LOGI("WiFi", "Remain OFF (Zigbee mode)");
    }
  }
  #endif

  // Defer settings screen outside LVGL event context (lock-protected)
  if (g_settingsRequested) {
    if (USE_LVGL_UI) {
      bool opened = false;
      if (LVGL_LOCK()) {
        lv_timer_t *t = lv_timer_create([](lv_timer_t *tm){ (void)tm; ui::showSettings(); }, 0, NULL);
        lv_timer_set_repeat_count(t, 1);
        lv_timer_t *t2 = lv_timer_create([](lv_timer_t *tm){ (void)tm; ui::setSavedWifi(g_storage.getWifiSsid("").c_str(), g_storage.getWifiPass("").c_str()); ui::setSavedMqtt(g_storage.getMqttHost("").c_str(), g_storage.getMqttPort(1883), g_storage.getMqttUser("").c_str(), g_storage.getMqttPass("").c_str()); }, 20, NULL);
        lv_timer_set_repeat_count(t2, 1);
        LVGL_UNLOCK(); opened = true;
      }
      if (opened) g_settingsRequested = false;
    } else {
      g_settingsRequested = false;
    }
  }


  // Avoid drawing directly with Arduino_GFX while LVGL UI is active

  // Dummy telemetry (optional) - enabled for all paths so baseline shows values
  if (DUMMY_MODE) {
    static uint32_t lastDummyLog = 0;
    updateDummyTelemetry();
    
    // Debug log every 5 seconds BEFORE UI update
    if (millis() - lastDummyLog > 5000) {
      lastDummyLog = millis();
      ESP_LOGI("DUMMY", "Generating: pH=%.2f ORP=%.0fmV Temp=%.1f°C", 
               domain::Metrics::instance().phVal, 
               domain::Metrics::instance().orpMv,
               domain::Metrics::instance().tempC);
    }
    
  }
  // updateLvglValues() already called at top of loop(); no need to repeat here

  // Read sensors (internal ADC or ADS1115) and update Metrics when enabled
  #if USE_ANALOG_SENSORS
  if (!DUMMY_MODE) {
    static uint32_t lastRead = 0;
    static uint32_t lastLog = 0;
    domain::Telemetry t{};
    if (g_analog.read(t)) {
      if (t.havePh)   { METRICS().phVal = t.phVal; METRICS().havePh = true; }
      if (t.haveOrp)  { METRICS().orpMv = t.orpMv; METRICS().haveOrp = true; }
      if (t.haveTemp) { METRICS().tempC = t.tempC; METRICS().haveTemp = true; }
      uint32_t now = millis();
      if (now - lastLog >= 2000) {
        lastLog = now;
        Serial.printf("[ANALOG] pH=%.3f (%.3fV)  ORP=%.0fmV (%.3fV)\n",
          t.havePh ? t.phVal : NAN, g_analog.sampleVoltsPh(),
          t.haveOrp ? t.orpMv : NAN, g_analog.sampleVoltsOrp());
      }
    }
  }
  #endif
  #if USE_ADS1115
  if (!DUMMY_MODE) {
    static uint32_t lastLog = 0;
    domain::Telemetry t{};
    if (g_ads.read(t)) {
      if (t.havePh)   { METRICS().phVal = t.phVal; METRICS().havePh = true; }
      if (t.haveOrp)  { METRICS().orpMv = t.orpMv; METRICS().haveOrp = true; }
      if (t.haveTemp) { METRICS().tempC = t.tempC; METRICS().haveTemp = true; }
      uint32_t now = millis();
      if (now - lastLog >= 2000) {
        lastLog = now;
        char b[128];
        snprintf(b, sizeof(b), "[ADS1115] pH=%.3f (%.3fV)  ORP=%.0fmV (%.3fV)",
          t.havePh ? t.phVal : NAN, g_ads.sampleVoltsPh(),
          t.haveOrp ? t.orpMv : NAN, g_ads.sampleVoltsOrp());
        Serial.println(b);
        if (webui.isActive()) webui.log(b);
      }
    }
  }
  #endif

  // Start captive portal on request (e.g., after WiFi reset)
  if (g_startPortalRequested) {
    g_startPortalRequested = false;
    // Clear WiFiManager credentials to avoid STA attempts with empty SSID
    wifiMgr.setCredentials("", "");
    portal.setStorage(&g_storage);
    if (!portal.isActive()) portal.beginAP("Pura-Setup");
    if (USE_LVGL_UI) ui::setIp(WiFi.softAPIP().toString().c_str());
  }

  // UI task now handles lv_timer_handler on S3
  // Push live updates to WebUI websockets periodically
  static uint32_t lastWebPush=0;
  uint32_t nowMs = millis();
  if (WiFi.status()==WL_CONNECTED && nowMs - lastWebPush > 1000) {
    lastWebPush = nowMs;
    if (webui.isActive()) webui.broadcastMetrics();
  }

  // Feed the 24h sensor history (5-min averages for the WebUI sparklines)
  static uint32_t lastHistSample = 0;
  if (nowMs - lastHistSample > 5000) {
    lastHistSample = nowMs;
    domain::History::instance().sample();
  }

  // WiFi/MQTT service loop
  static uint32_t lastConnectAttempt = 0;
  uint32_t now = millis();
  
  
  if (!wifiOff) {
    if (runMode == core::Storage::MODE_WIFI_MQTT) {
      wifiMgr.loop();
      if (WiFi.status() == WL_CONNECTED) {
        // Only attempt MQTT if a host is configured
        if (MQTT_HOST.length() > 0) {
        if (!mqttClient.isConnected() && now - lastConnectAttempt > 5000) {
          lastConnectAttempt = now;
          mqttClient.ensureConnected();
        }
        if (mqttClient.isConnected()) {
          mqttClient.publishDiscoveryOnce();
          mqttClient.publishStatesIfReady(domain::Metrics::instance());
          mqttClient.loop();
        }
      }
    }
  }
  }

  #if !defined(USE_JC3248W535)
  // When LVGL UI is active (C6 on master), touch events are fed into LVGL input driver above
  // Legacy touch UI removed; LVGL indev handles touch
  #endif
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

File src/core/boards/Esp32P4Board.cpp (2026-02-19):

#include "Esp32P4Board.h"
#include <Arduino.h>
#include <lvgl.h>
#include <esp_log.h>

#if defined(BOARD_ESP32P4_43)
#include "boards/pins_config_p4.h"
#include "st7701_lcd.h"
#include "gt911_touch.h"
#include "driver/i2c_master.h"

// File-scope display/touch objects (owned here, not in main.cpp)
static st7701_lcd            s_lcd(LCD_RST);
static gt911_touch           s_touch(TP_I2C_SDA, TP_I2C_SCL, TP_RST, TP_INT);
static bsp_lcd_handles_t     s_lcd_panels;
// Non-static: GT911 driver retrieves it via i2c_master_get_bus_handle(I2C_NUM_1)
i2c_master_bus_handle_t      p4_i2c_handle = NULL;

// LVGL draw buffers (allocated in PSRAM during initDisplay)
static lv_disp_draw_buf_t    s_draw_buf;
static lv_color_t           *s_buf  = nullptr;
static lv_color_t           *s_buf1 = nullptr;

// Sync touch rotation with display rotation
static void p4_rotation_cb(lv_disp_drv_t *drv) {
    switch (drv->rotated) {
    case LV_DISP_ROT_NONE:   s_touch.set_rotation(0); break;
    case LV_DISP_ROT_90:     s_touch.set_rotation(1); break;
    case LV_DISP_ROT_180:    s_touch.set_rotation(2); break;
    case LV_DISP_ROT_270:    s_touch.set_rotation(3); break;
    }
}
#endif // BOARD_ESP32P4_43

namespace core {

void Esp32P4Board::earlyInit() {
    // P4: display and touch init happen in initDisplay(); nothing needed here
}

void Esp32P4Board::initPeripherals() {
    // P4 uses ESP-IDF i2c_master API for touch (I2C_NUM_1); do not call Wire.begin()
    // C6 UART bridge: GPIO16 (RX) / GPIO17 (TX) — configured by ZigbeeClient when needed
}

BoardPins Esp32P4Board::pins() const {
    return BoardPins{
        .lcdBl     = -1,   // TBD — adjust for actual board wiring
        .btn1      = -1, .btn2   = -1,
        .motorStby = 11,
        .m1in1     = 12, .m1in2  = 13, .m1pwm = 14,
        .m2in1     = 15, .m2in2  = 36, .m2pwm = 37,
        .i2sBclk   = -1, .i2sLrc = -1, .i2sDin = -1, // no speaker on P4 yet
    };
}

lv_disp_t* Esp32P4Board::initDisplay() {
#if defined(BOARD_ESP32P4_43)
    ESP_LOGI("BOARD", "P4: Initialising MIPI-DSI display (480x800)");

    // ── I2C for touch (I2C_NUM_1) ──────────────────────────────────────────
    i2c_master_bus_config_t i2c_cfg = {
        .i2c_port            = I2C_NUM_1,
        .sda_io_num          = (gpio_num_t)TP_I2C_SDA,
        .scl_io_num          = (gpio_num_t)TP_I2C_SCL,
        .clk_source          = I2C_CLK_SRC_DEFAULT,
        .glitch_ignore_cnt   = 7,
        .intr_priority       = 0,
        .trans_queue_depth   = 0,
        .flags               = {.enable_internal_pullup = 1},
    };
    i2c_new_master_bus(&i2c_cfg, &p4_i2c_handle);

    // ── LCD + touch ────────────────────────────────────────────────────────
    s_lcd.begin();
    s_touch.begin();           // uses i2c_master_get_bus_handle(I2C_NUM_1) internally
    s_touch.set_rotation(0);   // portrait; transform in the LVGL read_cb
    s_lcd.get_handle(&s_lcd_panels);

    ESP_LOGI("BOARD", "P4: LCD + touch initialised");

    // ── LVGL init ──────────────────────────────────────────────────────────
    lv_init();

    size_t buf_bytes = sizeof(lv_color_t) * LCD_V_RES * 100; // 800 × 100 lines
    s_buf  = (lv_color_t *)heap_caps_malloc(buf_bytes, MALLOC_CAP_SPIRAM);
    s_buf1 = (lv_color_t *)heap_caps_malloc(buf_bytes, MALLOC_CAP_SPIRAM);
    assert(s_buf && s_buf1 && "P4: Failed to allocate LVGL buffers in PSRAM");

    lv_disp_draw_buf_init(&s_draw_buf, s_buf, s_buf1, LCD_V_RES * 100);

    static lv_disp_drv_t disp_drv;
    lv_disp_drv_init(&disp_drv);
    disp_drv.hor_res       = LCD_H_RES;   // 480
    disp_drv.ver_res       = LCD_V_RES;   // 800
    disp_drv.draw_buf      = &s_draw_buf;
    disp_drv.full_refresh  = false;
    disp_drv.sw_rotate     = 1;
    disp_drv.rotated       = LV_DISP_ROT_270; // landscape
    disp_drv.drv_update_cb = p4_rotation_cb;
    disp_drv.flush_cb      = [](lv_disp_drv_t *drv, const lv_area_t *area, lv_color_t *color_p) {
        (void)drv;
        s_lcd.lcd_draw_bitmap(area->x1, area->y1, area->x2 + 1, area->y2 + 1, &color_p->full);
    };

    lv_disp_t *disp = lv_disp_drv_register(&disp_drv);

    // DPI panel transfer-done → notify LVGL
    esp_lcd_dpi_panel_event_callbacks_t cbs = {0};
    cbs.on_color_trans_done = [](esp_lcd_panel_handle_t, esp_lcd_dpi_panel_event_data_t *, void *user_ctx) -> bool {
        lv_disp_drv_t *drv = (lv_disp_drv_t *)user_ctx;
        if (drv) lv_disp_flush_ready(drv);
        return false;
    };
    esp_lcd_dpi_panel_register_event_callbacks(s_lcd_panels.panel, &cbs, &disp_drv);
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

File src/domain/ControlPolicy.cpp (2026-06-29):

#include "ControlPolicy.h"
#include <Arduino.h>
#include "driver/ledc.h"
#include <esp_log.h>
#include <cmath>

namespace domain {

ControlPolicy::ControlPolicy(int stby, int m1_in1, int m1_in2, int m1_pwm, int m2_in1, int m2_in2, int m2_pwm)
  : _stby(stby), 
    _m1_in1(m1_in1), _m1_in2(m1_in2), _m1_pwm(m1_pwm),
    _m2_in1(m2_in1), _m2_in2(m2_in2), _m2_pwm(m2_pwm) {
  // Pin initialization is now handled by MotorController
  _lastPhSensorMs = millis();
  _lastOrpSensorMs = millis();
}

void ControlPolicy::triggerAlert(SafetyAlert alert) {
  _lastAlert = alert;
  _emergencyStop = true;
  
  // Log the alert
  const char* alertNames[] = {
    "NONE", "DAILY_LIMIT_M1", "DAILY_LIMIT_M2", 
    "SESSION_VOLUME_M1", "SESSION_VOLUME_M2",
    "SESSION_DURATION_M1", "SESSION_DURATION_M2",
    "PH_SANITY_LOW", "PH_SANITY_HIGH",
    "ORP_SANITY_LOW", "ORP_SANITY_HIGH",
    "PH_SENSOR_TIMEOUT", "ORP_SENSOR_TIMEOUT"
  };
  ESP_LOGE("SAFETY", "ALERT: %s - Emergency stop activated!", alertNames[(int)alert]);
  
  // Call callback if registered
  if (_alertCallback) {
    _alertCallback(alert);
  }
}

bool ControlPolicy::checkSafety(const ControlConfig& cfg, bool havePh, float phVal, bool haveOrp, float orpMv) {
  if (_emergencyStop) return false;  // Already in emergency stop
  
  uint32_t now = millis();
  
  // 1. Check sensor timeouts
  if (cfg.sensorTimeoutSec > 0) {
    if (!havePh && (now - _lastPhSensorMs) > ((uint32_t)cfg.sensorTimeoutSec * 1000UL)) {
      triggerAlert(SafetyAlert::PH_SENSOR_TIMEOUT);
      return false;
    }
    if (!haveOrp && (now - _lastOrpSensorMs) > ((uint32_t)cfg.sensorTimeoutSec * 1000UL)) {
      triggerAlert(SafetyAlert::ORP_SENSOR_TIMEOUT);
      return false;
    }
  }
  
  // Update last valid sensor times
  if (havePh) {
    _lastPhSensorMs = now;
    
    // 2. Check pH sanity
    if (phVal < cfg.phSanityMin) {
      triggerAlert(SafetyAlert::PH_SANITY_LOW);
      return false;
    }
    if (phVal > cfg.phSanityMax) {
      triggerAlert(SafetyAlert::PH_SANITY_HIGH);
      return false;
    }
    
    // Check for sudden jumps (> 1.0 pH in 1 sec) - skip on first reading to avoid
    // a permanent lockout when the live value differs from the 7.0 default.
    if (_phPrimed && fabsf(phVal - _lastValidPh) > 1.0f) {
      ESP_LOGW("SAFETY", "pH sudden jump detected: %.2f -> %.2f (ignoring)", _lastValidPh, phVal);
      return false;
    }
    _lastValidPh = phVal;
    _phPrimed = true;
  }
  
  if (haveOrp) {
    _lastOrpSensorMs = now;
    
    // 3. Check ORP sanity
    if (orpMv < cfg.orpSanityMin) {
      triggerAlert(SafetyAlert::ORP_SANITY_LOW);
      return false;
    }
    if (orpMv > cfg.orpSanityMax) {
      triggerAlert(SafetyAlert::ORP_SANITY_HIGH);
      return false;
    }
    
    // Check for sudden jumps (> 300 mV in 1 sec) - skip on first reading
    if (_orpPrimed && fabsf(orpMv - _lastValidOrp) > 300.0f) {
      ESP_LOGW("SAFETY", "ORP sudden jump detected: %.0f -> %.0f (ignoring)", _lastValidOrp, orpMv);
      return false;
    }
    _lastValidOrp = orpMv;
    _orpPrimed = true;
  }
  
  // 4. Check daily volume limits
  if (cfg.maxDailyVolumeMl > 0) {
    if (_m1Stats.dailyVolumeMl >= cfg.maxDailyVolumeMl) {
      triggerAlert(SafetyAlert::DAILY_LIMIT_M1);
      return false;
    }
    if (_m2Stats.dailyVolumeMl >= cfg.maxDailyVolumeMl) {
      triggerAlert(SafetyAlert::DAILY_LIMIT_M2);
      return false;
    }
  }
  
  // 5. Check session volume limits (only for running pumps)
  if (cfg.maxSessionVolumeMl > 0) {
    if (_m1Stats.sessionStartMs > 0 && _m1Stats.sessionVolumeMl >= cfg.maxSessionVolumeMl) {
      triggerAlert(SafetyAlert::SESSION_VOLUME_M1);
      return false;
    }
    if (_m2Stats.sessionStartMs > 0 && _m2Stats.sessionVolumeMl >= cfg.maxSessionVolumeMl) {
      triggerAlert(SafetyAlert::SESSION_VOLUME_M2);
      return false;
    }
  }
  
  // 6. Check session duration limits (only for running pumps)
  if (cfg.maxSessionDurationSec > 0) {
    if (_m1Stats.sessionStartMs > 0) {
      uint32_t m1Duration = (now - _m1Stats.sessionStartMs) / 1000;
      if (m1Duration >= cfg.maxSessionDurationSec) {
        triggerAlert(SafetyAlert::SESSION_DURATION_M1);
        return false;
      }
    }
    if (_m2Stats.sessionStartMs > 0) {
      uint32_t m2Duration = (now - _m2Stats.sessionStartMs) / 1000;
      if (m2Duration >= cfg.maxSessionDurationSec) {
        triggerAlert(SafetyAlert::SESSION_DURATION_M2);
        return false;
      }
    }
  }
  
  return true;  // All safety checks passed
}

void ControlPolicy::updatePumpStats(PumpStats &stats, uint32_t &lastStartMs, uint8_t &lastSpeedPc,
                                    bool isRunning, uint8_t speedPc, float flowRateMlPerMin) {
  uint32_t now = millis();
  
  if (isRunning) {
    // Motor is running
    if (lastStartMs == 0) {
      // Motor just started - begin new session
      lastStartMs = now;
      lastSpeedPc = speedPc;
      stats.sessionStartMs = now;
      stats.sessionVolumeMl = 0.0f;  // Reset session volume
    } else {
      // Motor was already running - accumulate volume
      uint32_t elapsedMs = now - lastStartMs;
      float elapsedMin = elapsedMs / 60000.0f;
      float volumeMl = (lastSpeedPc / 100.0f) * flowRateMlPerMin * elapsedMin;
      
      stats.totalVolumeMl += volumeMl;
      stats.dailyVolumeMl += volumeMl;
      stats.sessionVolumeMl += volumeMl;
      stats.totalRuntimeMs += elapsedMs;
      lastStartMs = now;
      lastSpeedPc = speedPc;
    }
    // Update current flow rate
    stats.currentFlowMlMin = (speedPc / 100.0f) * flowRateMlPerMin;
  } else {
    // Motor stopped
    if (lastStartMs != 0) {
      // Motor just stopped - accumulate final period
      uint32_t elapsedMs = now - lastStartMs;
      float elapsedMin = elapsedMs / 60000.0f;
      float volumeMl = (lastSpeedPc / 100.0f) * flowRateMlPerMin * elapsedMin;
      
      stats.totalVolumeMl += volumeMl;
      stats.dailyVolumeMl += volumeMl;
      stats.sessionVolumeMl += volumeMl;
      stats.totalRuntimeMs += elapsedMs;
      lastStartMs = 0;
      lastSpeedPc = 0;
      stats.sessionStartMs = 0;
    }
    stats.currentFlowMlMin = 0.0f;
  }
}
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

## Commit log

2025-09-12 First Zigbee implementation
    [ota_zigbee_4MB.csv]
2025-09-13 WIP zigbee sensors
2025-09-13 Settings screen cleanup and zigbee bugfix
    [main.cpp]
2025-09-14 Readme update and zigbee / wifi toggle fix
    [main.cpp]
2025-09-17 ESP32-S3-JC3248W535 board added
    [default_16MB.csv]
2025-09-22 UI fixes and further main cleanup
    [Touch.cpp, main.cpp]
2025-09-25 Temperature colored tile
2025-09-25 ADS1115 and ESP32 ADC sensor readings
2025-10-02 Added flow and fixed touch
    [AdsPhOrpSensor.cpp, AdsPhOrpSensor.h, ControlPolicy.cpp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]
2025-10-06 Initial P4 board added
2025-10-09 Pump flow fix in ui
    [main.cpp]
2025-10-21 Add ESP32-P4 display libraries (st7701_lcd + gt911_touch)
    - Added st7701_lcd library for MIPI-DSI LCD driver
    - Added gt911_touch library for capacitive touch driver
    - Libraries moved from lib_p4 to libraries folder
    - Working configuration with direct initialization in main.cpp
2026-02-06 build: Generate PlatformIO build artifacts for ESP32P4 project, including LVGL, ESP32P4_Display, and GT911 touch libraries.
2026-02-06 feat: Add new STEP models for various components, STL files and a Python script for the case, and update `main.cpp`.
    [CTP09.step, LM2596.stp, PH-4502C.STEP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]
2026-02-07 refactor: Redesign case and lid components, introducing modular pump case parts and a new pump model.
    [CTP09.step, Grothen-3x5-Peristaltic-Pump.STEP, case.step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]
2026-02-07 fix: refine mounting hole detection logic and adjust motor cutout diameter for pump case lid.
    [pump_case_bucket.step, pump_case_lid.step, pump_case_lid.stl]
2026-02-07 feat: Add USB-C connector and update case designs for full assembly.
    [USB-C.stp, case.step, case.stl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]
2026-02-07 fix: color changes
    [case.step, case.stl, lid.step]
2026-02-07 feat: Update case and lid designs and regenerate the full assembly.
    [case.step, lid.step, lid.stl]
2026-02-07 feat: Add 'PoolLab' text as a flush inlay to the lid, refactor export logic, and include new font files.
    [case.step, lid.step, lid.stl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]
2026-02-07 feat: Update CAD design files and generation script for the case and lid components.
    [case.step, lid.step, lid.stl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]
2026-02-08 refactor: Redesign lid screen cutout and implement new recessed mounting brackets.
    [case.step, lid.step, lid.stl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]
2026-02-08 feat: Adjust BNC Z-position and PCB Z-offset, reposition GX12, sensors, and other modules, restore USB-C clearance, and remove CTP09 wall cutout.
    [case.step, case.stl, ctp09_debug.step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]
2026-02-08 feat: Adjust component positions and update geometry in CAD designs for case and lid.
    [case.step, case.stl, ctp09_debug.step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]
2026-02-09 feat: Update CAD models with dimensional adjustments to the case and lid.
    [case.step, case.stl, ctp09_debug.step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]
2026-02-09 feat: add power management with IP5306 and ADC support, update device CAD designs, and introduce an I2C scanner.
    [case.step, ctp09_debug.step, lid.step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]
2026-02-10 feat: Implement web console and TelnetStream integration, alongside minor CAD design file updates.
    [case.step, ctp09_debug.step, lid.step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]
2026-02-10 feat: Refine case pillar cutout and adjust internal component positions for GX12, sensors, and modules.
    [case.step, case.stl, ctp09_debug.step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]
2026-02-17 feat: Add speaker support with UI control and resolve motor PWM timer conflicts for motor 1 and 2.
    [case.step, case.stl, ctp09_debug.step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]
2026-02-18 feat: Enhance board support with unified Board class, implement board-specific configurations, and integrate CallMeBot API key management in storage.
2026-02-19 refactor: Remove unused Zigbee code and implement UI configuration structure for board-specific settings.
2026-02-19 feat: Replace Tuya sniffer with direct analog pH/ORP/Temp sensing, update platform to ESP32-S3, and clean up old files.
    [AnalogPhOrpSensor.h, main.cpp]
2026-02-19 feat: implement LVGL task heartbeat, refine dummy sensor mode, and remove obsolete pin configurations and test files.
2026-02-19 Refactor UI scrolling and watchdog heartbeat logic, and update mechanical designs.
    [case.step, case.stl, ctp09_debug.step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]
2026-05-26 fix(ui): throttle WiFi/NVS/power polling in LVGL updateValues to prevent screen freeze
    Refresh IP/SSID/MQTT/battery/mode only once every ~10 ticks (~5s) instead of
    every 500ms tick. These APIs can block for several ms and stall the LVGL task,
    which froze the screen.
2026-05-26 feat(case): relocate USB-C PD trigger to right wall + add printable mount test fixture
    - case.py: remove the panel-mount USB-C; place the CTP09 PD trigger flat on the
    floor against the right wall with its USB-C facing out through a wall cutout;
    reorient the snap-fit mount (guide wall inward); run from repo root via os.chdir.
    - Add designs/ctp09_mount_test.py: standalone printable fixture to dial in the
    clip clamp height/strength, the back-wall power-wire slot, diode clearance, and
    the faceplate + inner pocket so the USB-C socket sits near-flush with the wall.
    These refinements will be ported back into case.py once the print fit is confirmed.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
    [case.step, case.stl, ctp09_debug.step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]
2026-05-26 feat(case): finalize CTP09 PD-trigger mount and integrate into the case
    Port the print-validated mount from designs/ctp09_mount_test.py into case.py:
    - clips clamp the bare PCB (clamp_t=1.0) with a 0.5mm tilt-in gap; thicker/wider
    arms (1.8/4.5) for strength; clip pairs at X=+2/+7.5 straddle the side diode
    - -X back wall gets a central wire slot for the power leads
    - right-wall USB-C access: connector-sized slot (9.5x3.6) through a 0.6mm
    faceplate plus an inner PCB-edge pocket, so the socket sits near-flush while
    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
    [case.step, case.stl, ctp09_debug.step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]
2026-06-25 fix(webui): auto-reconnect WebSocket + server heartbeat to stop UI freeze
    The browser WebSocket had no onclose handler, so when the TCP connection
    dropped (NAT idle prune, WiFi blip, recycled client slot) the page froze on
    its last values while LVGL kept updating locally. Add client-side reconnect
    on the index and console pages, and enable server heartbeat to detect and
    prune dead client slots.
    [WebUI.cpp]
2026-06-29 feat(pcb): add Pura mainboard PCB + fix ORP sensor jitter
    PCB project (pcb/):
    - Tscircuit JSX source (pura-mainboard-noroute.tsx) with CH224K USB-PD,
    LM2596 buck, ADS1115 ADC, TB6612 motor driver, ADuM1250 + B0505S
    galvanic isolation, USB-C 16P receptacle
    - KiCad project (pura-mainboard-noroute.kicad/) with 0.2mm tracks,
    0.15mm clearance, dual GND/AGND pours (prio 3 iso island)
    - Silkscreen: Pura wave logo + pin labels on all headers
    - JLCPCB-ready: BOM (28 parts w/ LCSC #s) + CPL placements + gerbers
    - CH224K mount printable fixture (designs/ch224k_mount_test.*)
    Firmware (src/io/AdsPhOrpSensor.h):
    - Drop ADS data rate 128 SPS → 32 SPS (enables internal 50/60Hz hum
    rejection, ~4x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
    [case.step, case.stl, ch224k_mount_test.step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]
2026-06-30 chore(pcb): untrack KiCad lock + DRC report files
    Add ~*.lck and DRC.txt to .gitignore so KiCad project lock files
    no longer cause edit conflicts on a pulled-then-opened project.
2026-07-02 feat(webui): pool dimensions + Na₂CO₃ dosing hints + mobile CSS
    Storage: persist pool L×W×H (cm) with sane defaults (5×3×1.3m ≈ 19.5m³).
    WebUI /settings: new 🏊 Pool Dimensions section with live volume readout.
    WebUI banners: when pH < min, compute soda ash dose (75g × ΔpH × m³ rule
    of thumb) and show grams/kg in the alert. Prompts user to configure pool
    dimensions if unset.
    Mobile responsive (@media <640px): stack metric cards vertically, shrink
    digital readout 54→44px, stack doser rows, wrap action buttons, hide
    node IP in topbar, drop letter-spacing to prevent text overflow, set
    input font-size 14px to avoid iOS auto-zoom.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
    [Storage.cpp, WebUI.cpp]
2026-07-15 Pura rev 0.3: geroute board, gerbers, tooling + firmware history
    PCB (besteklaar, DRC-schoon, gerbers geverifieerd tegen bron):
    - rev 0.3 op 0805: datasheet-geverifieerde componenten (CH224K PD-fix,
    1k+1uF op VDD, 10k VBUS-sense, TB6612 op 3V3, ADuM side-swap, B0505S
    minimum-load) — zie VERIFICATIE-0.3.md
    - volautomatische flow (build_flow.py): tsx -> KiCad -> freerouting
    headless -> zones/stitching -> DRC. port_zones.py + preroute_iso.py
    voor het AGND-isolatie-eiland en de gelockte iso/AIN pre-routes
    - netklassen (POWER 0.6mm), 3D-modellen, silkscreen (polariteit als
    diodesymbolen, connectorlabels ESP32/PROBES/12V/pH-ORP MOTOR, logo, v0.3)
    - gerbers + drill (67 gaten incl. USB-C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
    [pura-bom-basic.csv, pura-bom-tme.csv, pura-bom.csv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]
2026-08-02 pcb: BOM bijgewerkt naar definitieve inkoopkeuzes
    - L1: CD54/SRR-notitie vervangen door FerroCore DJNR6045-330 (33uH, 1.5A,
    6x6x4.5); past ~90% op het bestaande CD54-land (handsoldeer OK)
    - C_IN: 25V-keuze (EEE-1EA101XP) bevestigd; 16V EEEHC te krap op 12V-rail
    - C_OUT: Samwha SC1C227M6L07KVR (de daadwerkelijk bestelde 220uF/16V D8)
    - Bron-kolom toegevoegd (TME / Ali / module) zodat het lijstje klopt met
    wat er echt besteld wordt: 8 regels bij TME, rest Ali-assortiment/-chips
    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
    [pura-bom-tme.csv, pura-bom.csv, pura-self-source.csv]
2026-10-09 Pura rev 0.4: nieuwe plaatsing met rechte isolatieband + opnieuw opgebouwde schematic
    - build_04.py bouwt rev 0.4 uit de 0.3-netlist: PLACE-tabel, keepout-band
    y=103.2..104.8 (gaat als keepout mee in de DSN zodat freerouting hem niet
    kruist), rand-keepouts, freerouting headless, SES-import, zone-fill met
    AGND-stitching, barriere-check, DRC (courtyard-overlap = harde fout), renders
    - plaatsingscheck rekent met echte lichamen (elco-bus, header-kunststof) en
    pad-tot-rand; elco's >= 1,0 mm vrij van buren
    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
2026-10-09 Case v8 in FreeCAD, 0.3-board U2-orientatie, FreeCAD/STEP-export van de PCB
    - designs/case_freecad.py bouwt de nieuwe case (104x102x38) via de FreeCAD MCP;
    case.FCStd en case_v8.FCStd toegevoegd, STEP/STL-exports opnieuw gegenereerd
    - pcb 0.3: 3D-model van U2 (LM2596) gecorrigeerd (rotatie 90 -> 270, offset)
    - pcb 0.3: FreeCAD-model en gefuseerde STEP-export van het board toegevoegd
    - 3dmodels-symlink in de 0.4-map naar de 0.3-modellen
    - Claude-permissies voor dit project bijgewerkt
